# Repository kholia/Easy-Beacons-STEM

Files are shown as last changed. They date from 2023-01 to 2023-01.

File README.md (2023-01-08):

### Easy Beacons

A simple and easy Raspberry Pi Pico powered WSPR, and FT8 beacon system which
uses GPS for timing.

Note: The whole project can be assembled on a breadboard (including the [~100mW
amplifier](./QRPp-Amplifier-v2)) in under an hour - do give it a go!

The whole design is modular, parametric (cost and others), field repairable,
and super extensible. It is almost trivial to add support for more `beacon
modes`.

#### Build Steps

Use a stable version of the Arduino IDE 1.8.19 or later to build the project.

If you are on Linux, execute the following steps:

```
sudo apt-get install git  # install 'git' if needed

git clone https://github.com/kholia/Easy-Beacons-STEM.git

make install_arduino_cli
make install_platform
make deps
```

If you are using Windows OS, execute the following steps:

- Download this repository.

- Extract the downloaded zip file to a folder.

- Run the `setup_arduino_ide.bat` file inside this folder.

Note: Change the following lines in the code to use your values:

```
char message[] = "VU3CER VU3FOE MK68";
char call[] = "VU3FOE";
char loc[] = "MK68";
uint8_t dbm = 27;
```

#### Amplified-WSPR-Beacon

- Do NOT power with more than 8.4v!

- Use an 7.5v AC adapter for continuous use

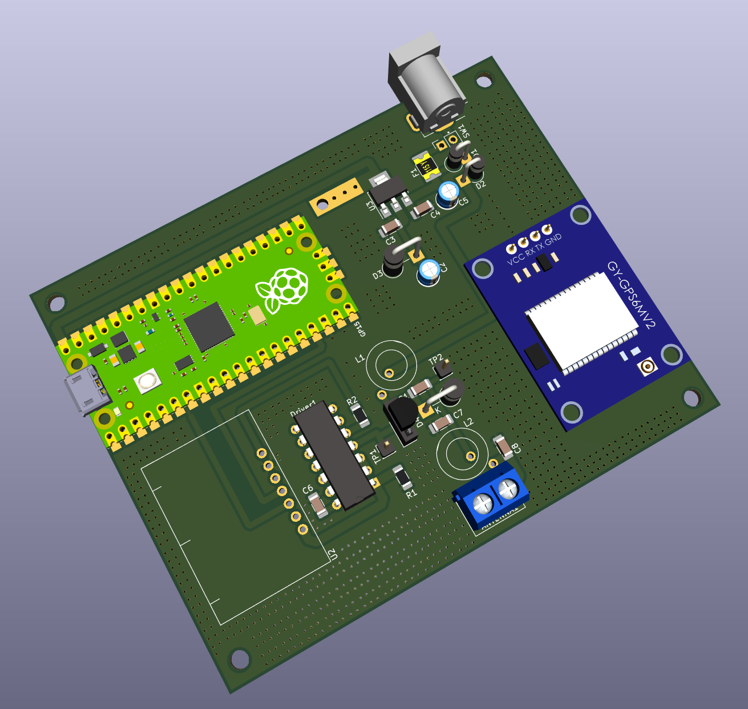
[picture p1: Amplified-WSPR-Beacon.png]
PCB Render


Note: The PCB version of the `Amplified-WSPR-Beacon` sub-project uses the `Pico-Beacons-GPS-v2` firmware (code).

Note 2: The `Amplified-WSPR-Beacon-v2` project uses 5v from USB.

#### Usage

When `SW1` switch is OFF, the system acts as a WSPR beacon.

When `SW1` switch is ON, the system acts as a FT8 beacon.

TIP: Please use a local (or nearby) receiver to receive and decode the beacon
signals! This is important to ensure that your beacon is TX'ing correctly.

#### Schematic

Here is the schematic for the `Pico-Beacons` sketch:

Pin 16 (GP16) is SDA and Pin 17 (GP17) is SCL - connect Si5351 module to these
pins. Connect GPS's TX pin to pin 12 (GP9) of Pi Pico.

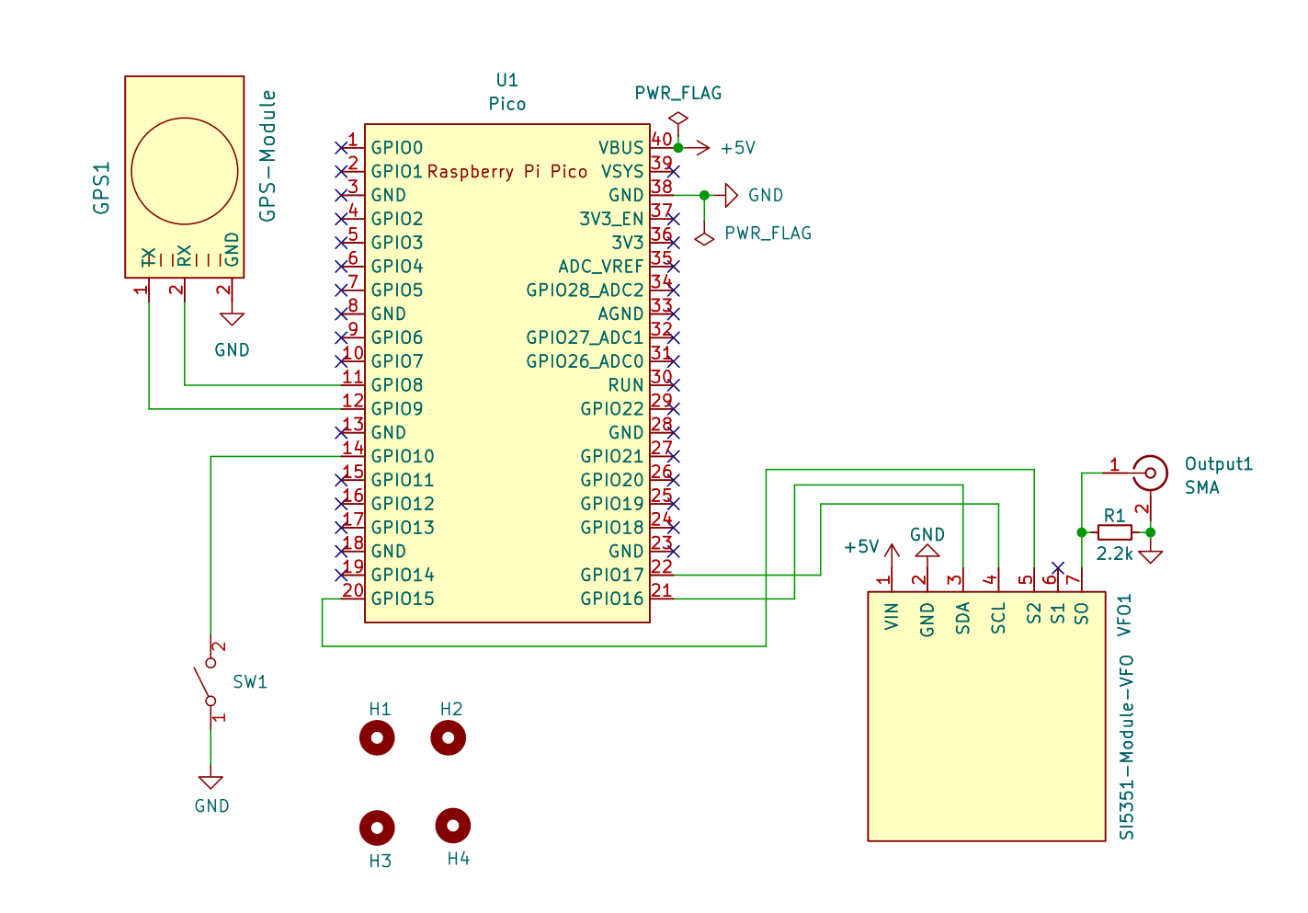
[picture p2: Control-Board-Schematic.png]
Schematic


#### Performance

7W (or less) of HF RF power offers global communications coverage when
propagation is good:

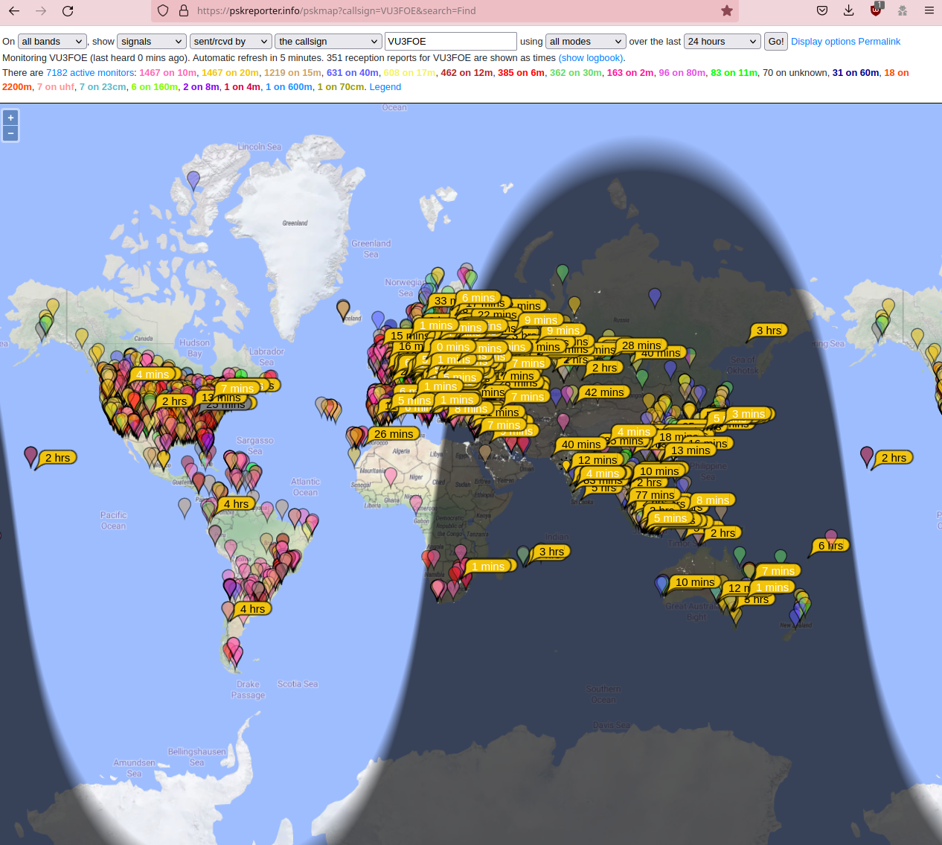
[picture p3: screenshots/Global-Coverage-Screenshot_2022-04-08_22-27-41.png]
Global Coverage

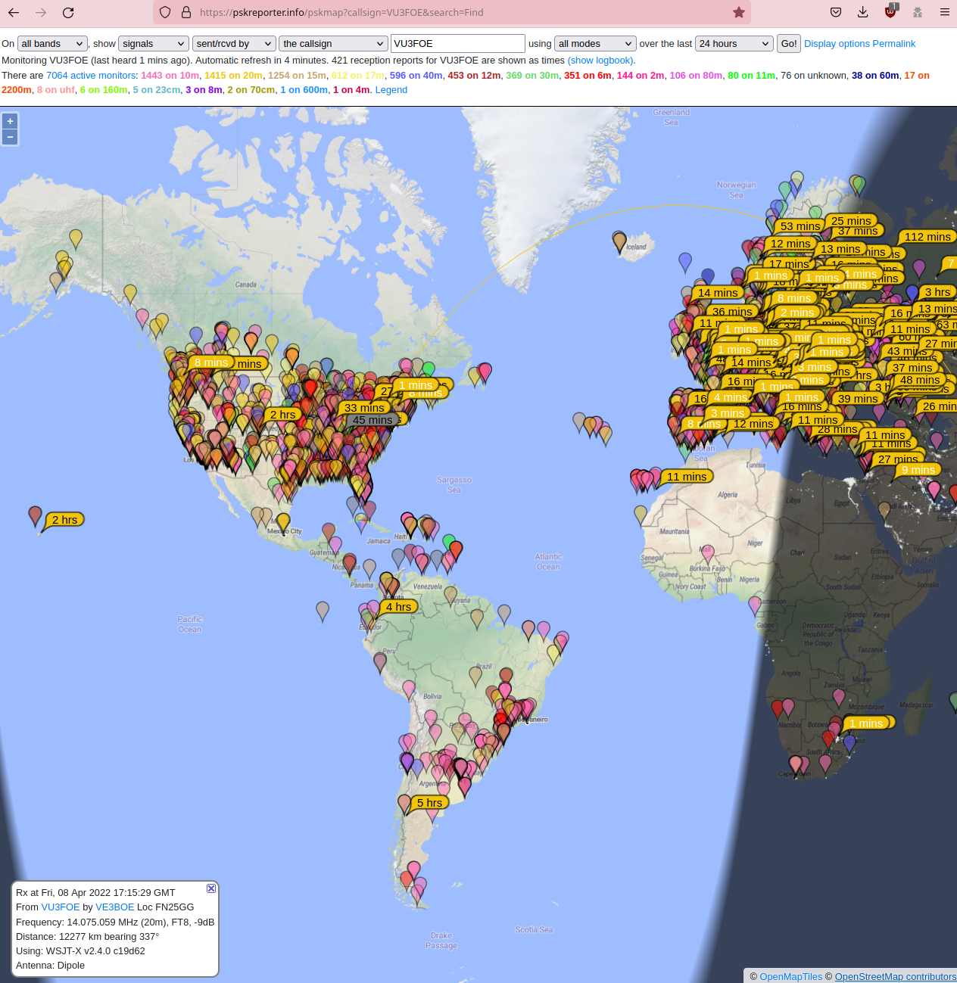
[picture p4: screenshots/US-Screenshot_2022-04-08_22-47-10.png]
US - Many Spots


WSPR mode demo:

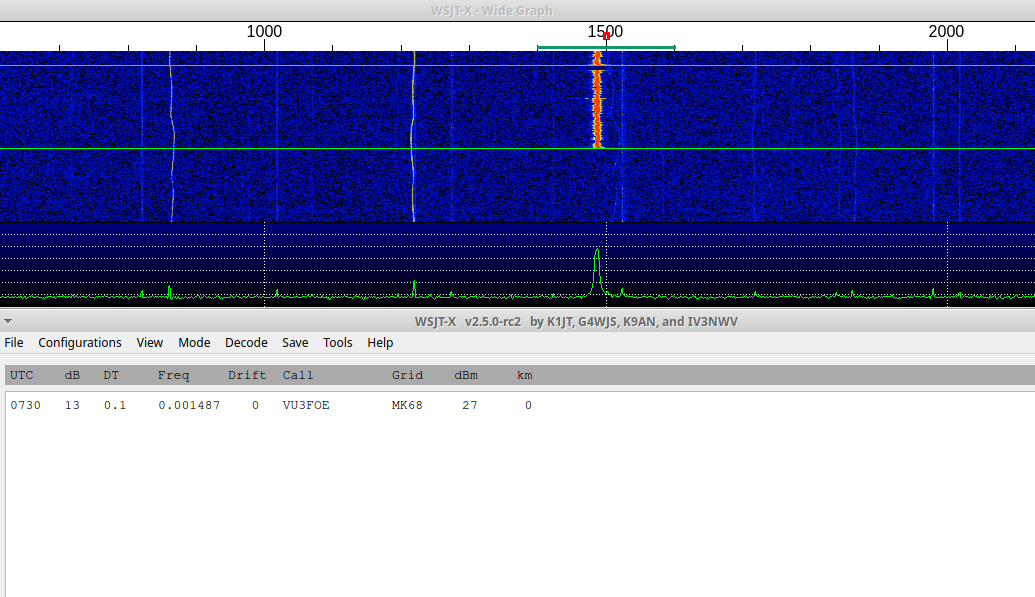
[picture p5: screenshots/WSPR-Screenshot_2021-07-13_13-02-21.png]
DEMO 1


#### Battery System Recommendation

I recommend using a LiFePo4 (LFP) battery which has good energy density and is
also priced decently well.

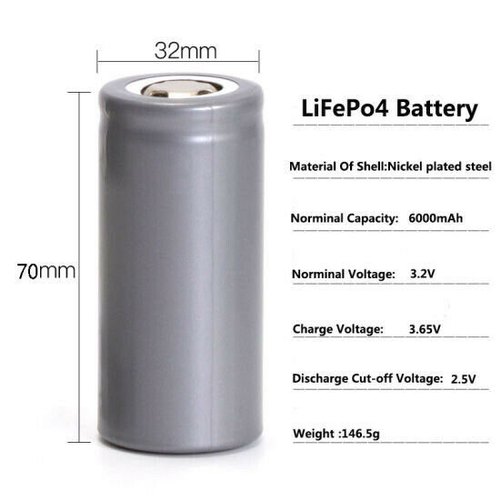
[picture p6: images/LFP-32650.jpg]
32650 battery


Use the LFP battery with a `1S LFP BMS`.

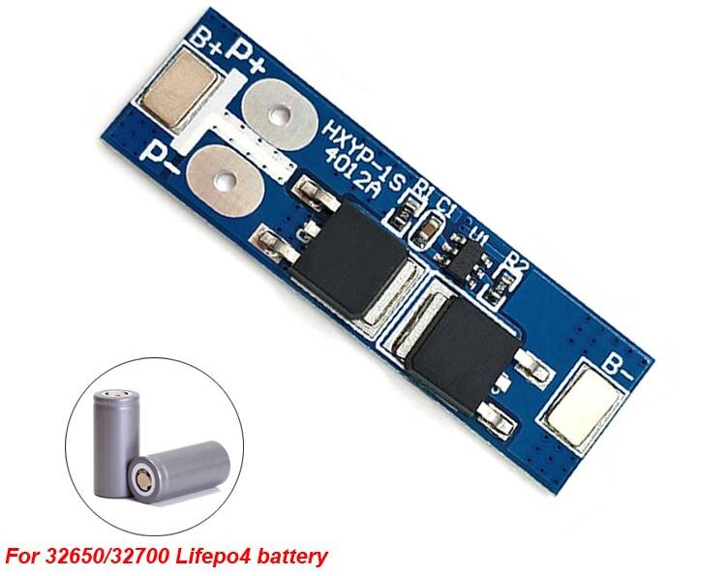
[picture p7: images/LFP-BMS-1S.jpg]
1S LFP BMS


The BMS' output can be connected directly to the 3.3v input of the ESP8266
module.

https://www.waveshare.com/wiki/Solar_Power_Manager - this `Solar Power
Management Module, for 6V~24V Solar Panel` works pretty well.

#### Power Notes

This will need a HF RF PA in many cases to be usable on the air.

You can also start with the easy-to-build and breadboard-friendly [QRPp-Amplifier-v2](./QRPp-Amplifier-v2).

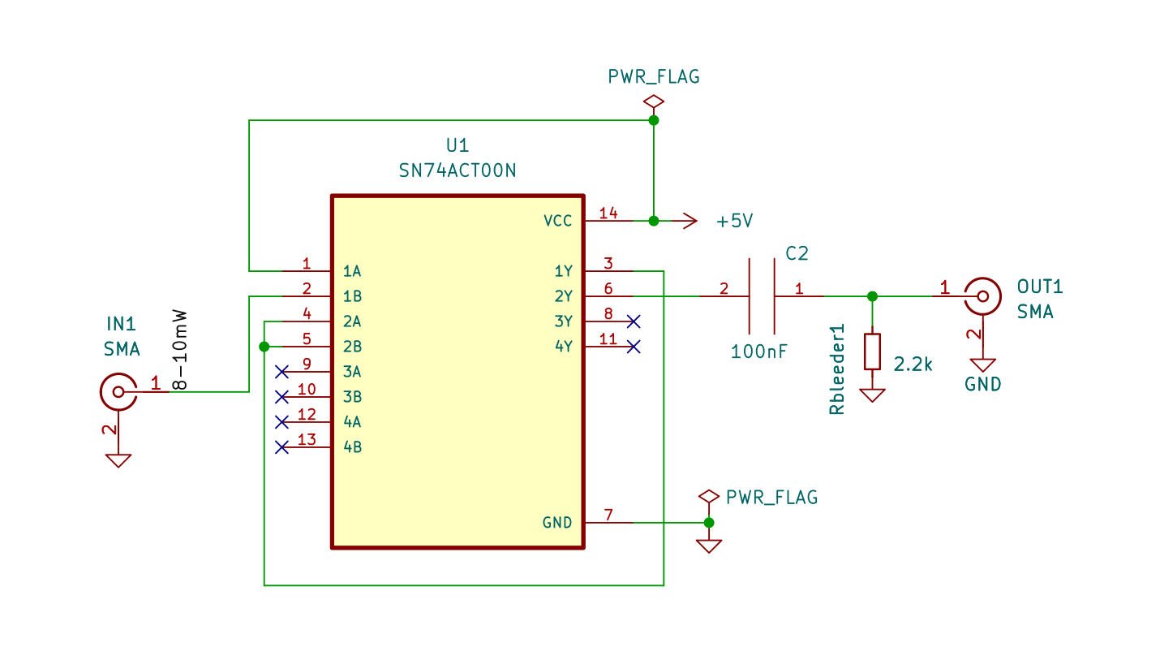
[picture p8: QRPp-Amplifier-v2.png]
QRPp-Amplifier-v2


#### Safety Notes

- Connect a 1k or 2.2k resistor between Si5351 CLK outputs and GND.

- Connect a series 100nF at Si5351 CLK outputs.

- Do NOT connect a LED to the output(s) of Si5351 directly. Use a 330 or 470
  ohm resistor in series or use a transistor driver at the Si5351 outputs
  (better).

#### Compliance Notes

Please use a LPF at the output.

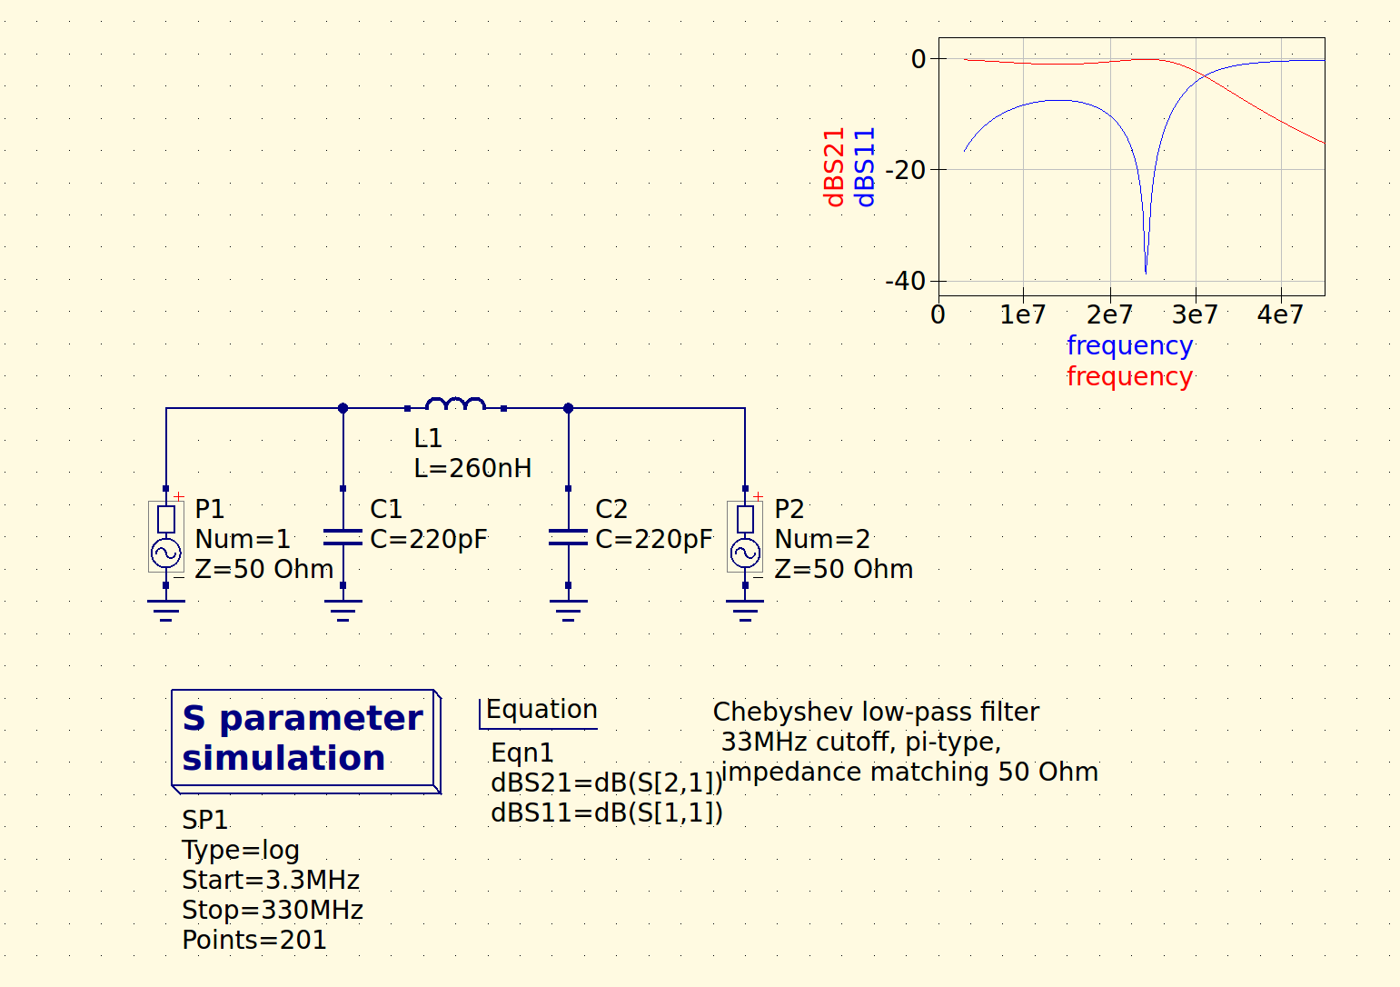
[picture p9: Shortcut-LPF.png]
Shortcut LPF


#### Gotchas

- https://github.com/mikalhart/TinyGPSPlus/issues/30 (NEO-6M modules can be buggy)

#### BOM

- 1 x 3/5mm LED (purple or pink is recommended)

- 1 x small regular (spst) chassis mount switch

- 1 x 0.25w 470 ohm resistor (CFR / MFR)

- High quality dupont cables / jumper cables

- Couple of 100nF 50V MLCC

- Zero PCB of a suitable size

- Raspberry Pi Pico board

- GPS module - NEO-7-M or better

- BS170 MOSFET (original only)

- SN74ACT00N (DIP 14 NAND Logic IC)

- Si5351A Module

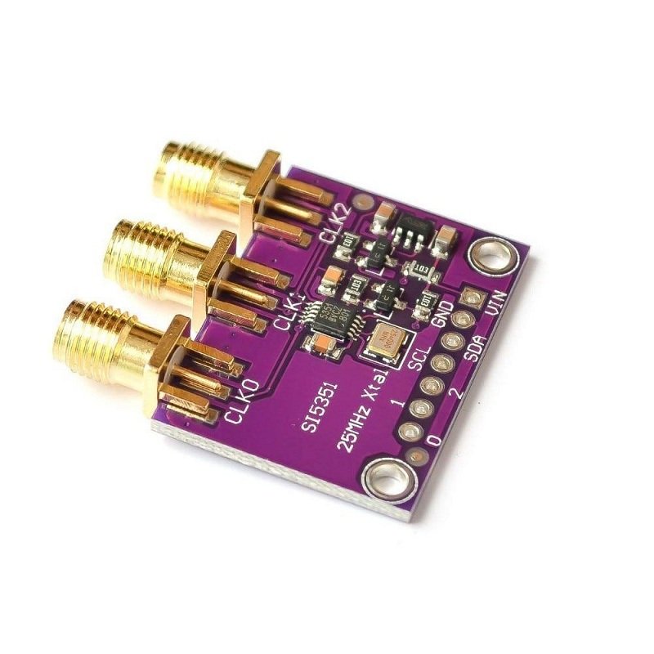
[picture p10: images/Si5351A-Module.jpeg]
Part 1
  

#### Install the firmware on Pi Pico

- Hold down the BOOTSEL button on your Pico (keep holding it down) and plug it
  into your computer's USB port.

  Now release the BOOTSEL button.

- Open Explorer, and open the RPI-RP2 directory like you would any other hard
  drive.

- Drag and drop the UF2 file (`firmware.uf2`) from this folder into the RPI-RP2
  directory.

- Done ;)

#### Build from source

Use the latest Arduino IDE along with https://github.com/earlephilhower/arduino-pico
to build this source code.

#### Next Steps

Check out the ADX and PDX radio designs for added fun!

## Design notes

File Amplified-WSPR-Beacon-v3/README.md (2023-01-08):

### Easy Beacons

A simple and easy Raspberry Pi Pico W powered WSPR, and FT8 beacon system which
uses RTC (DS3231) for timing.

The whole design is modular, parametric (cost and others), field repairable,
and super extensible. It is almost trivial to add support for more `beacon
modes`.

Cost to build: Less than 2300 INR (< 28 USD).

Cost breakdonw: PCB (175) + Si5351 module (479) + Pico W (649) + Octal Driver
chip (85) + Passives (50) + Connectors (25) + Toroids (40) + RTC module (275) +
Wire (30) + Wire Ferrules (10) + Misc (50) + 425 (TR1).

Power output: 250mW even @ 28 MHz with a 5v supply (via USB).

Note: The kit needs to be (soldering) friendly enough - it will be built by
senior folks as well as young kids.

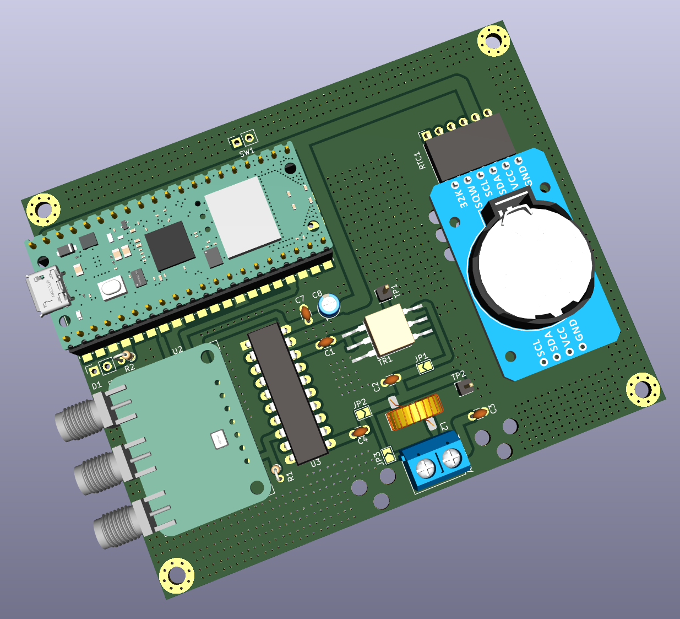
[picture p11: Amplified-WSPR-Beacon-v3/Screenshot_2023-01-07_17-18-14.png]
PCB render


#### Build Steps

Use a stable version of the Arduino IDE 1.8.19 or later to build the project.

If you are on Linux, execute the following steps:

```
sudo apt-get install git  # install 'git' if needed

git clone https://github.com/kholia/Easy-Beacons-STEM.git

make install_arduino_cli
make install_platform
make deps
```

If you are using Windows OS, execute the following steps:

- Download this repository.

- Extract the downloaded zip file to a folder.

- Run the `setup_arduino_ide.bat` file inside this folder.

Note: Change the following lines in the code to use your own values:

```
char call[] = "VU3CER";
char loc[] = "MK68";
uint8_t dbm = 23;
```

#### Amplified-WSPR-Beacon-v3

- Supply 5v to Raspberry Pico W using a mobile (phone) charger or a USB 5v
  battery bank.

Note: The PCB version of the `Amplified-WSPR-Beacon-v3` sub-project uses the
code from the `firmware` folder.

#### Usage

TIP: Please use a local (or nearby) receiver to receive and decode the beacon
signals! This is important to ensure that your beacon is calibrated and TX'ing
correctly.

#### Safety Notes

- Connect a 1k or 2.2k resistor between Si5351 CLK outputs and GND.

- Connect a series 100nF at Si5351 CLK outputs.

- Do NOT connect a LED to the output(s) of Si5351 directly. Use a 330 or 470
  ohm resistor in series or use a transistor driver at the Si5351 outputs
  (better).

#### BOM

- 1 x 3/5mm LED (purple or pink is recommended)

- 1 x 0.25W 2.2k ohms CFR / MFR (resistor)

- Couple of 100nF 50V MLCC caps

- 100uF/16V electrolytic caps

- 220pF C0G MLCC caps

- 27 to 29 SWG copper winding ("magnetic") wire

- PCB Terminal Block (5.08mm spacing, 2 holes)

- Raspberry Pi Pico W board

- DS3231 RTC module

- SN74ACT244N (Fast DIP-20 Octal Driver)

- T2-613-1 IC (1:1:2 transformer IC from Mini-Circuits)

- Si5351A Module (with TCXO preferably)

#### Install the firmware on Pi Pico

- Hold down the BOOTSEL button on your Pico (keep holding it down) and plug it
  into your computer's USB port.

  Now release the BOOTSEL button.

- Open Explorer, and open the RPI-RP2 directory like you would any other hard
  drive.

- Drag and drop the UF2 file (`firmware.uf2`) from this folder into the RPI-RP2
  directory.

- Done ;)

#### Build from source

Use the latest Arduino IDE along with https://github.com/earlephilhower/arduino-pico
to build this source code.

#### Next Steps

Check out the "DDX - Direct Digital Transceiver" design for added fun!

#### Tips

- https://en.wikipedia.org/wiki/Electric_wire_ferrule - Use wire ferrules for the antenna wires

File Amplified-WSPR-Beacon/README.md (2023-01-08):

Output with 7.4v @ drain is around 400mW @ 28 MHz. Not too bad - twice that of
the `Intl. WSPR Beacon` device.

This project is also called the `Rogue Radio - v1` ;)

Cost: < 1800 INR (not including the 2s 18650 battery pack) which is around 22
USD.

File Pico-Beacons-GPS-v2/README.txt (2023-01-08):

This code is for the `PCB version` of `Amplified-WSPR-Beacon` project.

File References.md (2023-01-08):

#### References + Credits

- https://github.com/kholia/Easy-Transceiver

- https://github.com/kgoba/ft8_lib

- https://github.com/etherkit/JTEncode

- https://github.com/Naguissa/uEEPROMLib

- https://randomnerdtutorials.com/esp8266-web-server-spiffs-nodemcu/

- https://lastminuteengineers.com/ds3231-rtc-arduino-tutorial/

- https://learn.adafruit.com/adafruit-si5351-clock-generator-breakout/wiring-and-test

- https://github.com/agustinmartino/wsjt_transceiver

- https://github.com/agustinmartino/wsjtx_transceiver_interface

- https://www.qrp-labs.com/synth/ms5351m.html

- https://github.com/anupamsaikia - FT4 fixes - thanks!

- https://github.com/f4goh/WSPR (pretty cool)

- https://github.com/lu7did/PixiePi

- https://github.com/iw5ejm/multibandWSPR_nodeMCU

- https://km4nmp.com/2019/08/24/vfo-for-the-pixie-wiring-and-sketch-for-ad9850/

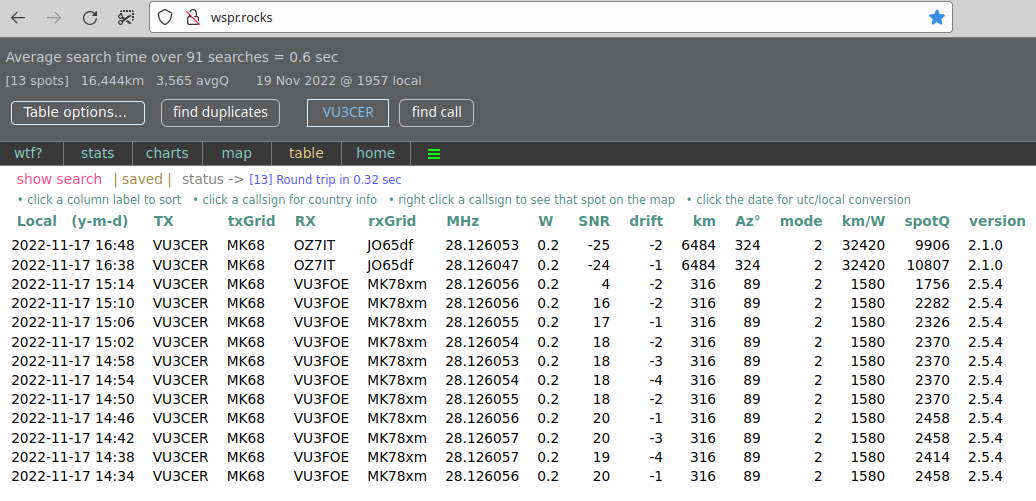
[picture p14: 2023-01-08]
Amplified-WSPR-Beacon/Report-Screenshot_2022-11-19_19-58-08.png

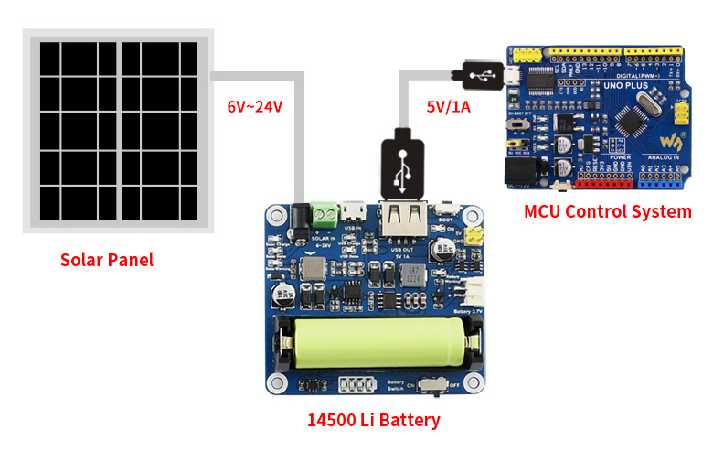
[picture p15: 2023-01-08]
images/Solar-Power-Manager-application.jpg

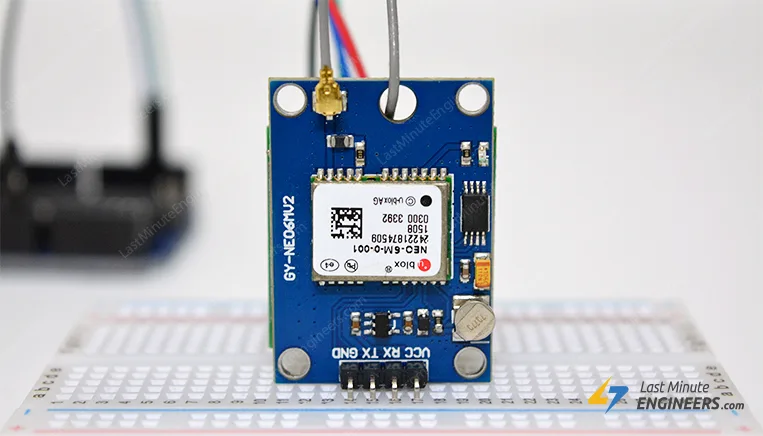
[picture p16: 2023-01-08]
images/NEO-6M-GPS-Module.webp

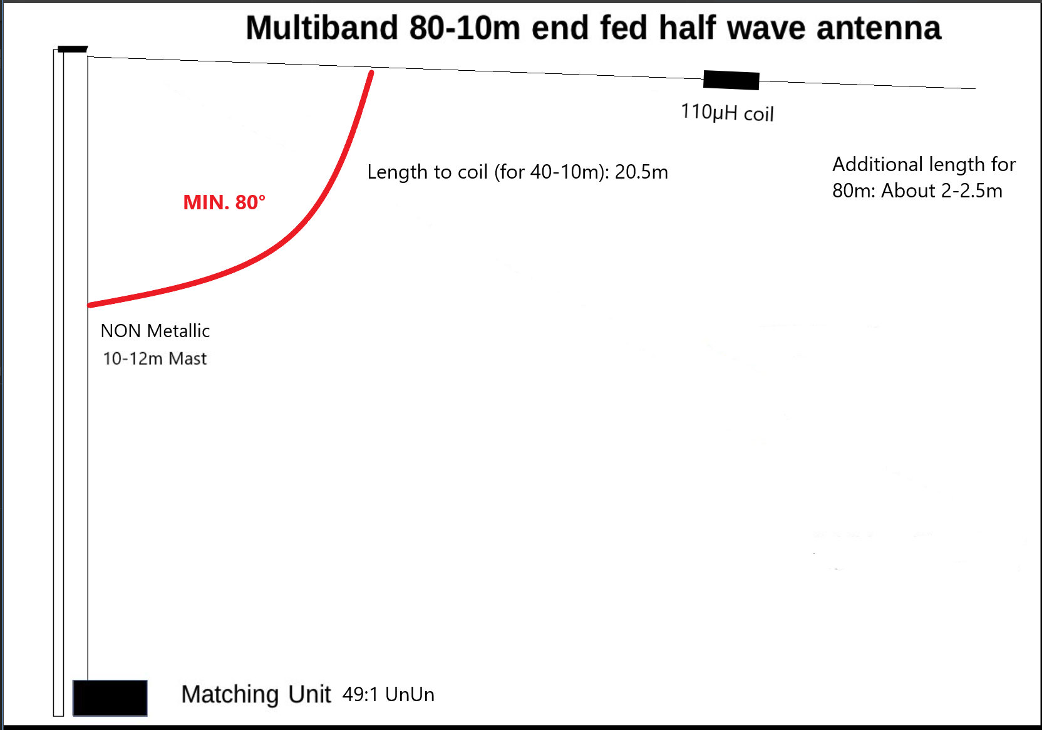
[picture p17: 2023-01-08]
EFHW-1-1.png

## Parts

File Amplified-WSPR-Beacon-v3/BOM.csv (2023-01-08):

Reference | Value | Footprint | Datasheet | Populate | URL | Qty
ANTENNA1 | Screw_Terminal_01x02 | TerminalBlock:TerminalBlock_bornier-2_P5.08mm | ~ | no | https://www.digikey.com/en/products/detail/weidm%C3%BCller/1760510000/459739 | 1
C1, C4, C7 | 100nF | Capacitor_THT:C_Disc_D3.0mm_W1.6mm_P2.50mm | ~ | no | https://www.digikey.com/en/products/detail/vishay-beyschlag-draloric-bc-components/K104K15X7RF5TL2/286538 | 3
C2, C3 | 220p | Capacitor_THT:C_Disc_D3.0mm_W1.6mm_P2.50mm | ~ | yes | https://www.digikey.in/en/products/detail/vishay-beyschlag-draloric-bc-components/K221J15C0GF5TL2/286471 | 2
C8 | 100uF/16V | Capacitor_THT:CP_Radial_D4.0mm_P2.00mm | ~ |  | https://www.digikey.com/en/products/detail/rubycon/16ZLH100MEFC5X11/3134106 | 1
D1 | LED | Connector_PinSocket_2.54mm:PinSocket_1x02_P2.54mm_Vertical | ~ |  |  | 1
H1-H4 | MountingHole_Pad | MountingHole:MountingHole_3.2mm_M3_Pad_Via | ~ |  |  | 4
JP1-JP3 | Jumper_2_Open | Jumper:SolderJumper-2_P1.3mm_Open_TrianglePad1.0x1.5mm | ~ |  |  | 3
L2 | 260nH (T50-6, ~8 turns) | footprints:T37-2 | https://toroids.info/T50-6.php | no | https://kitsandparts.com/ | 1
R1 | 2.2k | Resistor_THT:R_Axial_DIN0204_L3.6mm_D1.6mm_P1.90mm_Vertical | ~ | yes | https://www.digikey.com/en/products/detail/stackpole-electronics-inc/RNMF14FTC2K20/2617325 | 1
R2 | 470 | Resistor_THT:R_Axial_DIN0204_L3.6mm_D1.6mm_P1.90mm_Vertical | ~ |  | https://www.digikey.com/en/products/detail/yageo/MF0207FRE52-470R/9125108 | 1
RTC1 | RTC_DS3231_Inverted | Connector_PinSocket_2.54mm:PinSocket_1x06_P2.54mm_Horizontal |  | no | https://robu.in/product/1x40-berg-strip-right-angle-female-connector-5pcs/ | 1
TP1, TP2 | TestPoint | Connector_PinHeader_2.54mm:PinHeader_1x01_P2.54mm_Vertical | ~ | no | https://robu.in/product/1x40-berg-strip-male-connector/ | 2
TR1 | T2-613-1+ | footprints:KK81 | ~ |  | https://www.minicircuits.com/WebStore/dashboard.html?model=T2-613-1-KK81%2B | 1
U1 | Pico | footprints:RPi_Pico_SMD_TH |  | no | https://www.digikey.com/en/products/detail/raspberry-pi/SC0918/16608263 | 1
U2 | SI5351-Module-VFO (With TCXO) | footprints:SI5351 Module |  | no | https://www.adafruit.com/product/2045 | 1
U3 | 74ACT244 | Package_DIP:DIP-20_W7.62mm_LongPads | https://www.ti.com/product/SN74ACT244 | no | https://www.digikey.com/en/products/detail/texas-instruments/SN74ACT244N/375910 | 1

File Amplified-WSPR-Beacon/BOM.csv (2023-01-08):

Source: | Easy-Beacons-STEM/Amplified-WSPR-Beacon/Amplified-WSPR-Beacon.kicad_sch
Date: | Sun 20 Nov 2022 02:35:45 PM IST
Tool: | Eeschema 6.0.9-8da3e8f707~116~ubuntu22.04.1
Generator: | /usr/share/kicad/plugins/bom_csv_grouped_by_value.py
Component Count: | 33
Individual Components:
Item | Qty | Reference(s) | Value | LibPart | Footprint | Datasheet | Populate | URL
 |  | ANTENNA1 | Screw_Terminal_01x02 | Connector:Screw_Terminal_01x02 | TerminalBlock:TerminalBlock_bornier-2_P5.08mm | ~ | no | https://www.digikey.com/en/products/detail/weidm%C3%BCller/1760510000/459739
 |  | C1 | 100nF | Device:C | Capacitor_SMD:C_1206_3216Metric_Pad1.33x1.80mm_HandSolder | ~ | yes | https://www.digikey.com/en/products/detail/yageo/CC1206KRX7R9BB104/302913
 |  | C2 | 10uF/16V | Device:C_Polarized | Capacitor_THT:CP_Radial_D4.0mm_P2.00mm | ~ | no | https://www.digikey.com/en/products/detail/nichicon/UVR1C100MDD/588777
 |  | C3 | 100nF | Device:C | Capacitor_SMD:C_1206_3216Metric_Pad1.33x1.80mm_HandSolder | ~ | yes | https://www.digikey.com/en/products/detail/yageo/CC1206KRX7R9BB104/302913
 |  | C4 | 100nF | Device:C | Capacitor_SMD:C_1206_3216Metric_Pad1.33x1.80mm_HandSolder | ~ | yes | https://www.digikey.com/en/products/detail/yageo/CC1206KRX7R9BB104/302913
 |  | C5 | 100uF/16V | Device:C_Polarized | Capacitor_THT:CP_Radial_D4.0mm_P2.00mm | ~ | no | https://www.digikey.com/en/products/detail/rubycon/16YXF100MEFC6-3X11/3563101
 |  | C6 | 100nF | Device:C_Small | Capacitor_SMD:C_1206_3216Metric_Pad1.33x1.80mm_HandSolder | ~ | yes | https://www.digikey.com/en/products/detail/yageo/CC1206KRX7R9BB104/302913
 |  | C7 | 220p | Device:C_Small | Capacitor_SMD:C_1206_3216Metric_Pad1.33x1.80mm_HandSolder | ~ | yes | https://www.digikey.com/en/products/detail/yageo/CC1206JRNPO9BN221/2833598
 |  | C8 | 220p | Device:C_Small | Capacitor_SMD:C_1206_3216Metric_Pad1.33x1.80mm_HandSolder | ~ | yes | https://www.digikey.com/en/products/detail/yageo/CC1206JRNPO9BN221/2833598
 |  | D1 | 1N4007 | Diode:1N4007 | Diode_THT:D_DO-41_SOD81_P2.54mm_Vertical_KathodeUp | http://www.vishay.com/docs/88503/1n4001.pdf | no | https://www.digikey.com/en/products/detail/diodes-incorporated/1N4007-T/607
 |  | D2 | 1N4007 | Diode:1N4007 | Diode_THT:D_DO-41_SOD81_P2.54mm_Vertical_KathodeUp | http://www.vishay.com/docs/88503/1n4001.pdf | no | https://www.digikey.com/en/products/detail/diodes-incorporated/1N4007-T/607
 |  | D3 | 5.6V 5W | Device:D_Zener | Diode_THT:D_DO-15_P5.08mm_Vertical_KathodeUp | ~ | no | https://www.digikey.com/en/products/detail/onsemi/1N5339BRLG/822783
 |  | D4 | 47v 5W | Device:D_Zener | Diode_THT:D_DO-15_P5.08mm_Vertical_KathodeUp | ~ | no | https://www.digikey.in/en/products/detail/onsemi/1N5368BG/13476793
 |  | Driver1 | SN74ACT04N | SN74HC04N:SN74HC04N | Package_DIP:DIP-14_W7.62mm |  | no | https://www.digikey.com/en/products/detail/texas-instruments/SN74ACT04N/375794
 |  | F1 | 1A (PPTC) | Device:Polyfuse_Small | Fuse:Fuse_1812_4532Metric_Pad1.30x3.40mm_HandSolder | ~ | yes | https://www.digikey.com/en/products/detail/bourns-inc/MF-MSMF110-16-2/662820
 |  | GPS3 | GY-NEO6MV2-Module | GPS-Module:GPS-Module | Connector_PinSocket_2.54mm:PinSocket_1x04_P2.54mm_Vertical |  | no | https://quartzcomponents.com/products/neo6mv2-gps-module-with-flight-controller
 |  | H1 | MountingHole | Mechanical:MountingHole | MountingHole:MountingHole_3.2mm_M3 | ~ | no | N/A
 |  | H2 | MountingHole | Mechanical:MountingHole | MountingHole:MountingHole_3.2mm_M3 | ~ | no | N/A
 |  | H3 | MountingHole | Mechanical:MountingHole | MountingHole:MountingHole_3.2mm_M3 | ~ | no | N/A
 |  | H4 | MountingHole | Mechanical:MountingHole | MountingHole:MountingHole_3.2mm_M3 | ~ | no | N/A
 |  | HS1 | Heatsink_Pad | Mechanical:Heatsink_Pad | footprints:ThermalPad_Final | ~ | no | N/A
 |  | L1 | L | Device:L | footprints:FT37-INDUCTOR | FT37-43 | no | https://kitsandparts.com/
 |  | L2 | 260nH (T50-2, ~8 turns) | Device:L | footprints:FT37-INDUCTOR | FT50-2 | no | https://kitsandparts.com/
 |  | Power1 | DC-005 (Barrel Jack) | Connector:Barrel_Jack_Switch | footprints:XKB_DC-005-5A-2.0_Modded | ~ | no | https://www.lcsc.com/product-detail/Power-Connectors_XKB-Enterprise-DC-005-5A-2-0_C381116.html
 |  | Q1 | BS170 | Transistor_FET:BS170 | Connector_PinSocket_2.54mm:PinSocket_1x03_P2.54mm_Vertical | https://www.onsemi.com/pub/Collateral/BS170-D.PDF | no | https://www.tme.eu/en/details/bs170/tht-n-channel-transistors/onsemi/
 |  | R1 | 2.2k | Device:R_Small | Resistor_SMD:R_1206_3216Metric_Pad1.30x1.75mm_HandSolder | ~ | yes | https://www.digikey.com/en/products/detail/yageo/RT1206FRE072K2L/1083103
 |  | R2 | 2.2k | Device:R_Small | Resistor_SMD:R_1206_3216Metric_Pad1.30x1.75mm_HandSolder | ~ | yes | https://www.digikey.com/en/products/detail/yageo/RT1206FRE072K2L/1083103
 |  | SW1 | Jumper_2_Open | Jumper:Jumper_2_Open | Connector_PinSocket_2.54mm:PinSocket_1x02_P2.54mm_Vertical | ~ | no | https://www.digikey.com/en/products/detail/sullins-connector-solutions/QPC02SXGN-RC/2618262
 |  | TP1 | TestPoint | Connector:TestPoint | Connector_PinHeader_2.54mm:PinHeader_1x01_P2.54mm_Vertical | ~ | no | https://robu.in/product/1x40-berg-strip-male-connector/
 |  | TP2 | TestPoint | Connector:TestPoint | Connector_PinHeader_2.54mm:PinHeader_1x01_P2.54mm_Vertical | ~ | no | https://robu.in/product/1x40-berg-strip-male-connector/
 |  | U1 | Pico | pico_fixed:Pico | footprints:RPi_Pico_SMD_TH |  | no | https://www.digikey.com/en/products/detail/raspberry-pi/SC0915/13624793
 |  | U2 | SI5351-Module-VFO | Control-Board-rescue:SI5351Module_2-VFO-SDR_SSB-rescue-Hack-v1-rescue | footprints:SI5351 Module |  | no | https://www.adafruit.com/product/2045
 |  | U3 | NCP1117-5.0 | Regulator_Linear:AMS1117-5.0 | Package_TO_SOT_SMD:SOT-223-3_TabPin2 | http://www.advanced-monolithic.com/pdf/ds1117.pdf | yes | https://www.tme.com/in/en/details/ncp1117st50t3g/ldo-unregulated-voltage-regulators/onsemi/
Collated Components:
Item | Qty | Reference(s) | Value | LibPart | Footprint | Datasheet | Populate | URL
1 | 1 | ANTENNA1 | Screw_Terminal_01x02 | Connector:Screw_Terminal_01x02 | TerminalBlock:TerminalBlock_bornier-2_P5.08mm | ~ | no | https://www.digikey.com/en/products/detail/weidm%C3%BCller/1760510000/459739
2 | 3 | C1, C3, C4 | 100nF | Device:C | Capacitor_SMD:C_1206_3216Metric_Pad1.33x1.80mm_HandSolder | ~ | yes | https://www.digikey.com/en/products/detail/yageo/CC1206KRX7R9BB104/302913
3 | 1 | C2 | 10uF/16V | Device:C_Polarized | Capacitor_THT:CP_Radial_D4.0mm_P2.00mm | ~ | no | https://www.digikey.com/en/products/detail/nichicon/UVR1C100MDD/588777
4 | 1 | C5 | 100uF/16V | Device:C_Polarized | Capacitor_THT:CP_Radial_D4.0mm_P2.00mm | ~ | no | https://www.digikey.com/en/products/detail/rubycon/16YXF100MEFC6-3X11/3563101
5 | 1 | C6 | 100nF | Device:C_Small | Capacitor_SMD:C_1206_3216Metric_Pad1.33x1.80mm_HandSolder | ~ | yes | https://www.digikey.com/en/products/detail/yageo/CC1206KRX7R9BB104/302913
6 | 2 | C7, C8 | 220p | Device:C_Small | Capacitor_SMD:C_1206_3216Metric_Pad1.33x1.80mm_HandSolder | ~ | yes | https://www.digikey.com/en/products/detail/yageo/CC1206JRNPO9BN221/2833598
7 | 2 | D1, D2 | 1N4007 | Diode:1N4007 | Diode_THT:D_DO-41_SOD81_P2.54mm_Vertical_KathodeUp | http://www.vishay.com/docs/88503/1n4001.pdf | no | https://www.digikey.com/en/products/detail/diodes-incorporated/1N4007-T/607
8 | 1 | D3 | 5.6V 5W | Device:D_Zener | Diode_THT:D_DO-15_P5.08mm_Vertical_KathodeUp | ~ | no | https://www.digikey.com/en/products/detail/onsemi/1N5339BRLG/822783
9 | 1 | D4 | 47v 5W | Device:D_Zener | Diode_THT:D_DO-15_P5.08mm_Vertical_KathodeUp | ~ | no | https://www.digikey.in/en/products/detail/onsemi/1N5368BG/13476793
10 | 1 | Driver1 | SN74ACT04N | SN74HC04N:SN74HC04N | Package_DIP:DIP-14_W7.62mm |  | no | https://www.digikey.com/en/products/detail/texas-instruments/SN74ACT04N/375794
11 | 1 | F1 | 1A (PPTC) | Device:Polyfuse_Small | Fuse:Fuse_1812_4532Metric_Pad1.30x3.40mm_HandSolder | ~ | yes | https://www.digikey.com/en/products/detail/bourns-inc/MF-MSMF110-16-2/662820
12 | 1 | GPS3 | GY-NEO6MV2-Module | GPS-Module:GPS-Module | Connector_PinSocket_2.54mm:PinSocket_1x04_P2.54mm_Vertical |  | no | https://quartzcomponents.com/products/neo6mv2-gps-module-with-flight-controller
13 | 4 | H1, H2, H3, H4 | MountingHole | Mechanical:MountingHole | MountingHole:MountingHole_3.2mm_M3 | ~ | no | N/A
14 | 1 | HS1 | Heatsink_Pad | Mechanical:Heatsink_Pad | footprints:ThermalPad_Final | ~ | no | N/A
15 | 1 | L1 | L | Device:L | footprints:FT37-INDUCTOR | FT37-43 | no | https://kitsandparts.com/
16 | 1 | L2 | 260nH (T50-2, ~8 turns) | Device:L | footprints:FT37-INDUCTOR | FT50-2 | no | https://kitsandparts.com/
17 | 1 | Power1 | DC-005 (Barrel Jack) | Connector:Barrel_Jack_Switch | footprints:XKB_DC-005-5A-2.0_Modded | ~ | no | https://www.lcsc.com/product-detail/Power-Connectors_XKB-Enterprise-DC-005-5A-2-0_C381116.html
18 | 1 | Q1 | BS170 | Transistor_FET:BS170 | Connector_PinSocket_2.54mm:PinSocket_1x03_P2.54mm_Vertical | https://www.onsemi.com/pub/Collateral/BS170-D.PDF | no | https://www.tme.eu/en/details/bs170/tht-n-channel-transistors/onsemi/
19 | 2 | R1, R2 | 2.2k | Device:R_Small | Resistor_SMD:R_1206_3216Metric_Pad1.30x1.75mm_HandSolder | ~ | yes | https://www.digikey.com/en/products/detail/yageo/RT1206FRE072K2L/1083103
20 | 1 | SW1 | Jumper_2_Open | Jumper:Jumper_2_Open | Connector_PinSocket_2.54mm:PinSocket_1x02_P2.54mm_Vertical | ~ | no | https://www.digikey.com/en/products/detail/sullins-connector-solutions/QPC02SXGN-RC/2618262
21 | 2 | TP1, TP2 | TestPoint | Connector:TestPoint | Connector_PinHeader_2.54mm:PinHeader_1x01_P2.54mm_Vertical | ~ | no | https://robu.in/product/1x40-berg-strip-male-connector/
22 | 1 | U1 | Pico | pico_fixed:Pico | footprints:RPi_Pico_SMD_TH |  | no | https://www.digikey.com/en/products/detail/raspberry-pi/SC0915/13624793
23 | 1 | U2 | SI5351-Module-VFO | Control-Board-rescue:SI5351Module_2-VFO-SDR_SSB-rescue-Hack-v1-rescue | footprints:SI5351 Module |  | no | https://www.adafruit.com/product/2045
24 | 1 | U3 | NCP1117-5.0 | Regulator_Linear:AMS1117-5.0 | Package_TO_SOT_SMD:SOT-223-3_TabPin2 | http://www.advanced-monolithic.com/pdf/ds1117.pdf | yes | https://www.tme.com/in/en/details/ncp1117st50t3g/ldo-unregulated-voltage-regulators/onsemi/

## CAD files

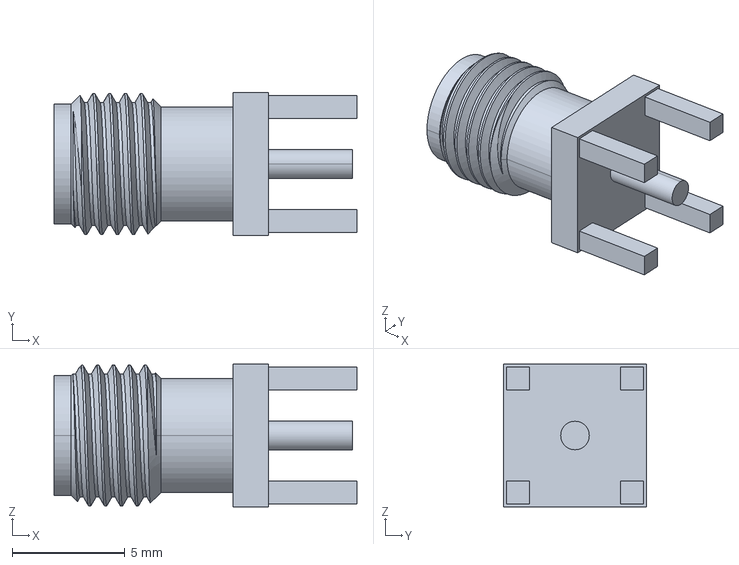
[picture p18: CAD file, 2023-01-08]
Amplified-WSPR-Beacon-v3/models/901-144.stp
13.5 x 6.35 x 6.35 mm

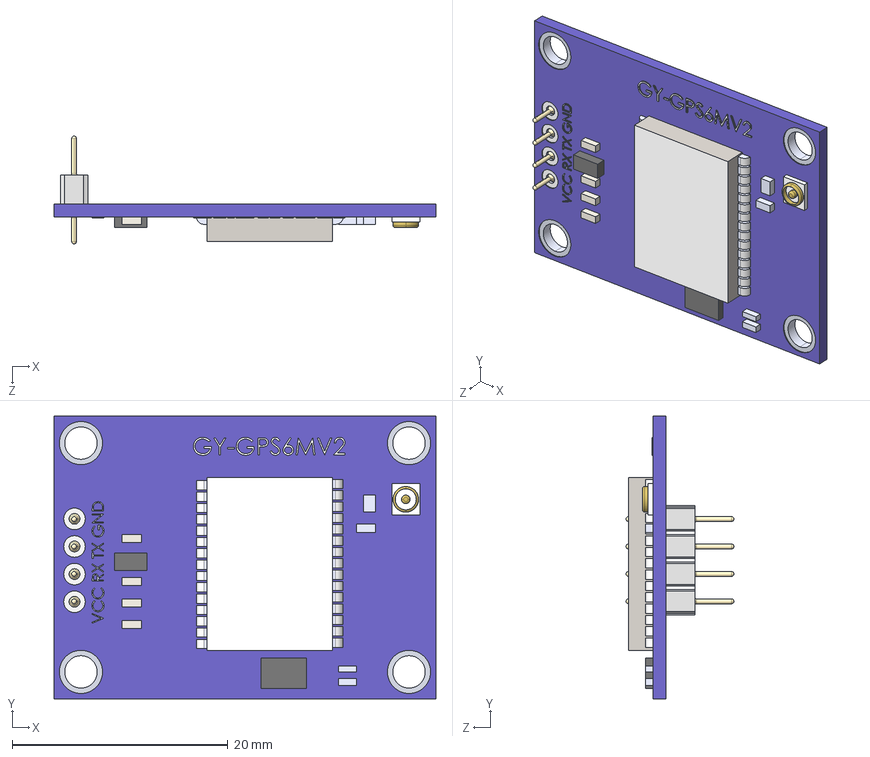
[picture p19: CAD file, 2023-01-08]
Amplified-WSPR-Beacon/models/GY-GPS6MV2 v1.STEP
35.4 x 26.2 x 10.0 mm

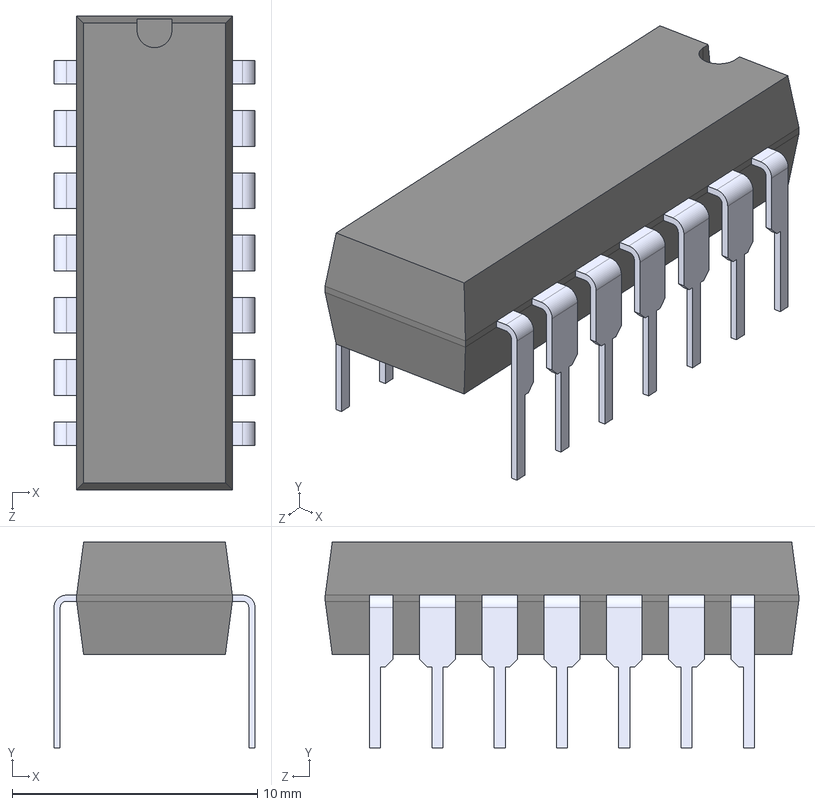
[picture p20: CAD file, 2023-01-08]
Amplified-WSPR-Beacon/SN74HC04N.step
8.19 x 8.38 x 19.3 mm

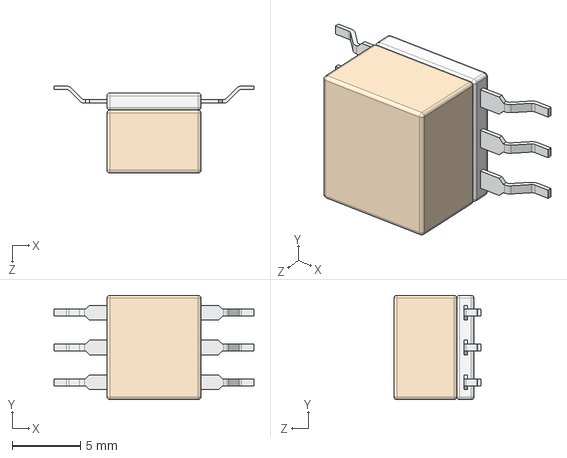
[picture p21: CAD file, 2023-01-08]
Amplified-WSPR-Beacon-v3/models/User Library-T4-6-KK81.STEP
14.6 x 7.62 x 6.35 mm

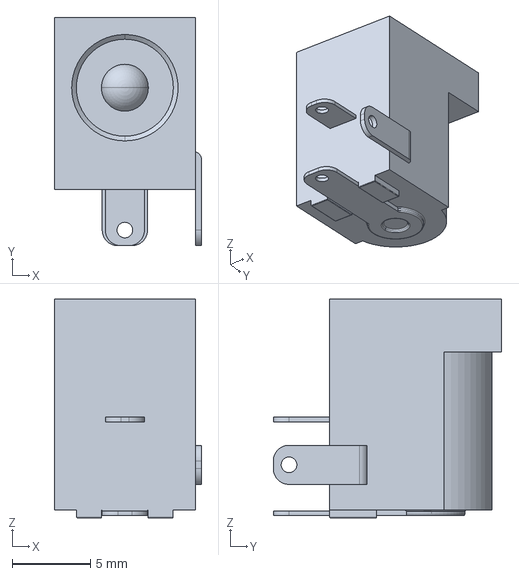
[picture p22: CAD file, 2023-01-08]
Amplified-WSPR-Beacon/models/DC-005-5A-2.0.step
9.40 x 14.6 x 14.0 mm

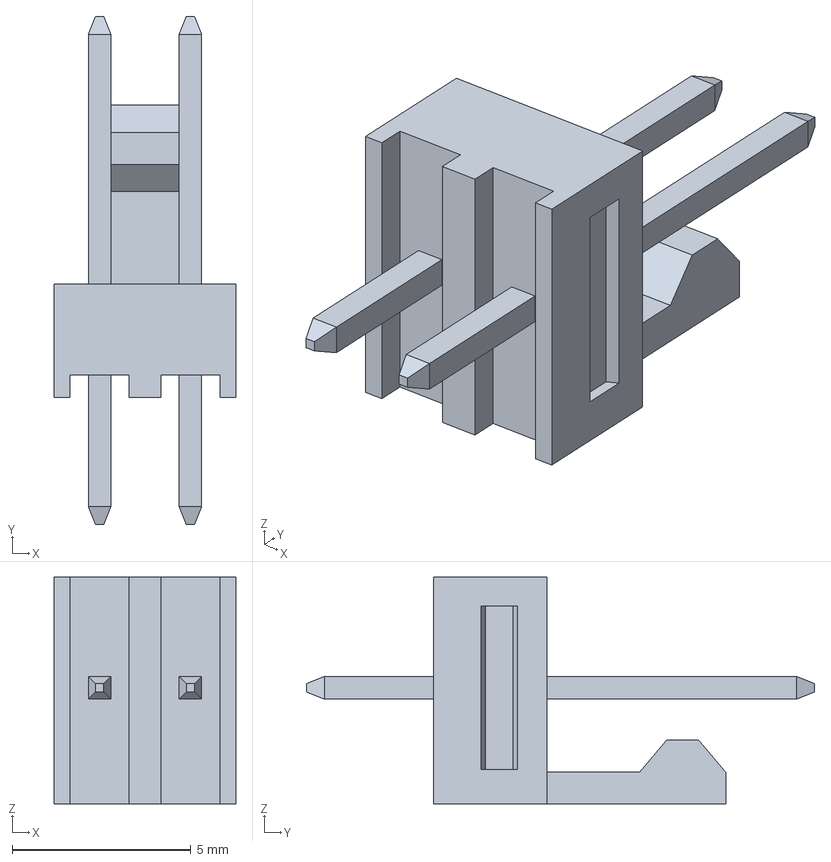
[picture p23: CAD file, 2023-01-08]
Amplified-WSPR-Beacon-v3/models/22-23-2021.stp
5.08 x 14.2 x 6.35 mm

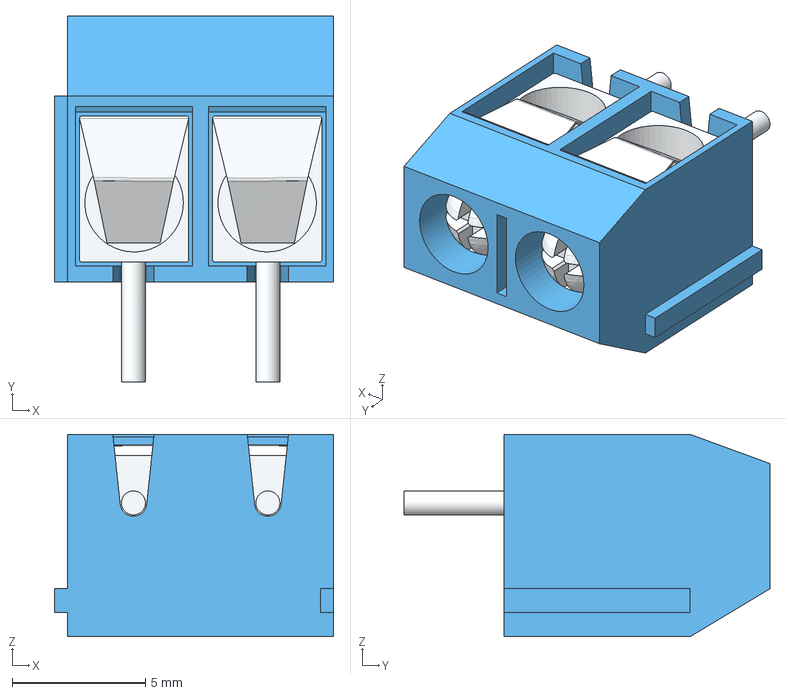
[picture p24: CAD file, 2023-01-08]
Amplified-WSPR-Beacon/models/bornera.step
10.5 x 13.8 x 7.60 mm

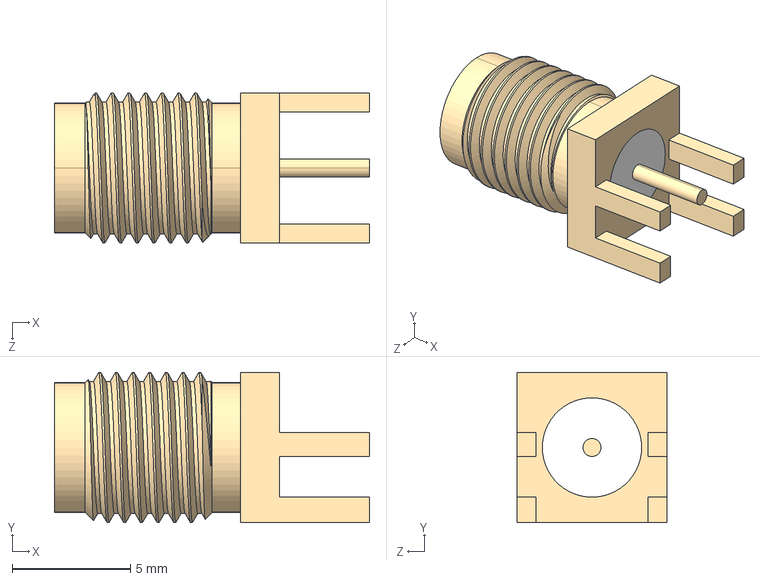
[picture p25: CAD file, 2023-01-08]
Amplified-WSPR-Beacon/models/CON-SMA-EDGE-S--3DModel-STEP-56544.STEP
13.3 x 6.35 x 6.35 mm

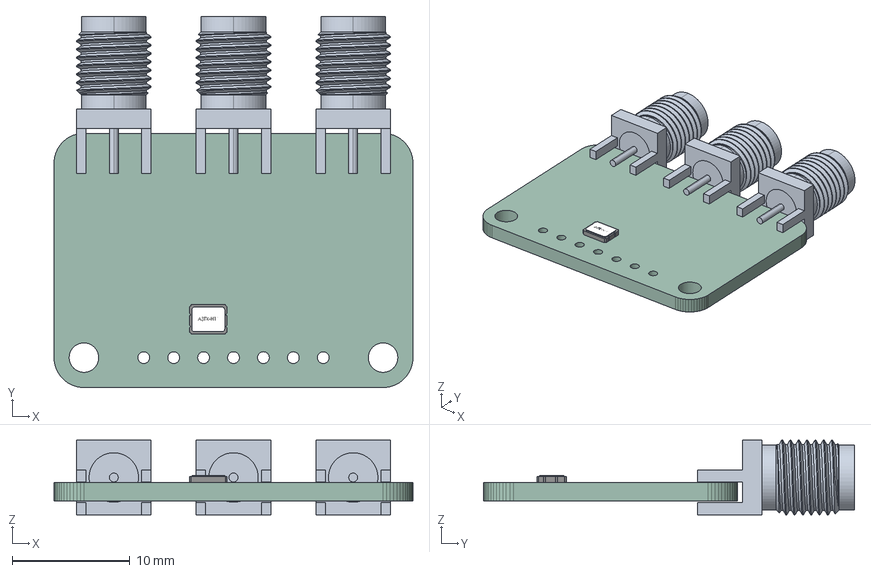
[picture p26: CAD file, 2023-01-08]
Amplified-WSPR-Beacon-v3/models/Adafruit Si5351A.step
30.5 x 31.5 x 6.35 mm
PCB

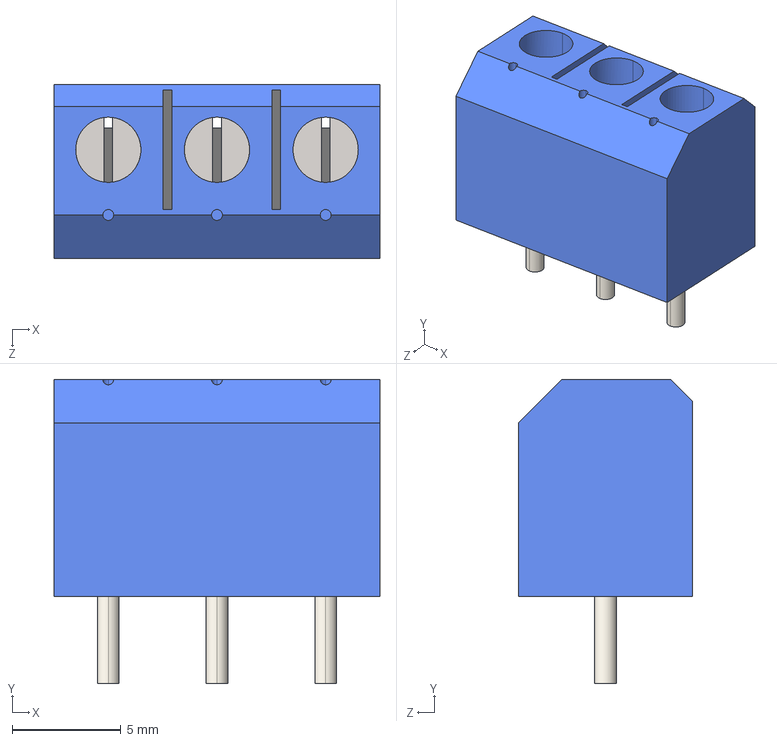
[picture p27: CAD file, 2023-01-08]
Amplified-WSPR-Beacon-v3/models/bornera de 3 terminales v2.0.STEP
15.0 x 14.0 x 8.00 mm

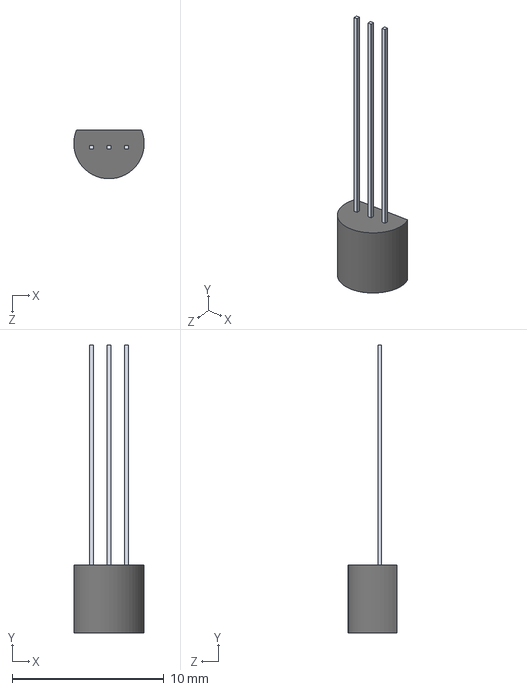
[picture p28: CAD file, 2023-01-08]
Amplified-WSPR-Beacon/models/Transistor_TO-92_Type.STEP
4.64 x 19.0 x 3.20 mm

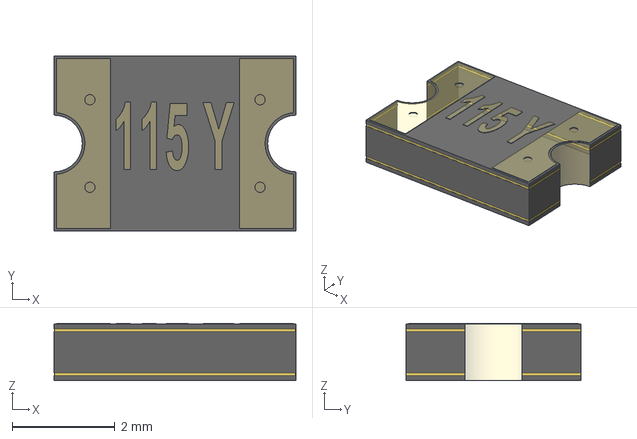
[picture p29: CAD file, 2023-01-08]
Amplified-WSPR-Beacon/models/smd1812.stp
4.70 x 3.40 x 1.11 mm

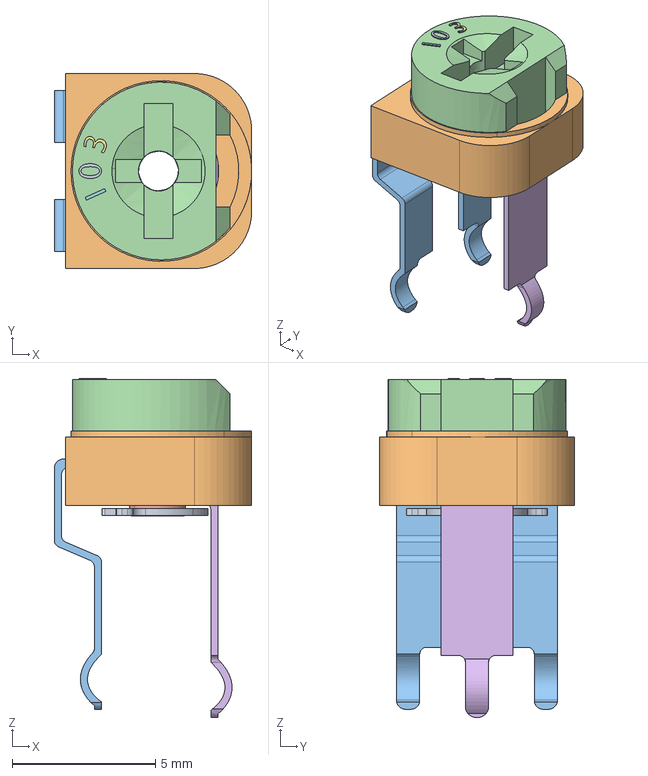
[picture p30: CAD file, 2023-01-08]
Amplified-WSPR-Beacon/models/Poti_10kohm.stp
6.88 x 6.80 x 11.8 mm

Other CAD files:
Amplified-WSPR-Beacon-v2/models/1564889-62.stp
Amplified-WSPR-Beacon-v2/models/1566143-62.stp
Amplified-WSPR-Beacon-v3/models/1564889-62.stp
Amplified-WSPR-Beacon-v3/models/1566143-62.stp
Amplified-WSPR-Beacon/models/1564889-62.stp
Amplified-WSPR-Beacon/models/1566143-62.stp
Amplified-WSPR-Beacon/models/24DR.STEP
Amplified-WSPR-Beacon/models/N0016A.stp
Amplified-WSPR-Beacon/models/User Library-TO-92-2_54-line.STEP
Amplified-WSPR-Beacon/models/pj-307.step

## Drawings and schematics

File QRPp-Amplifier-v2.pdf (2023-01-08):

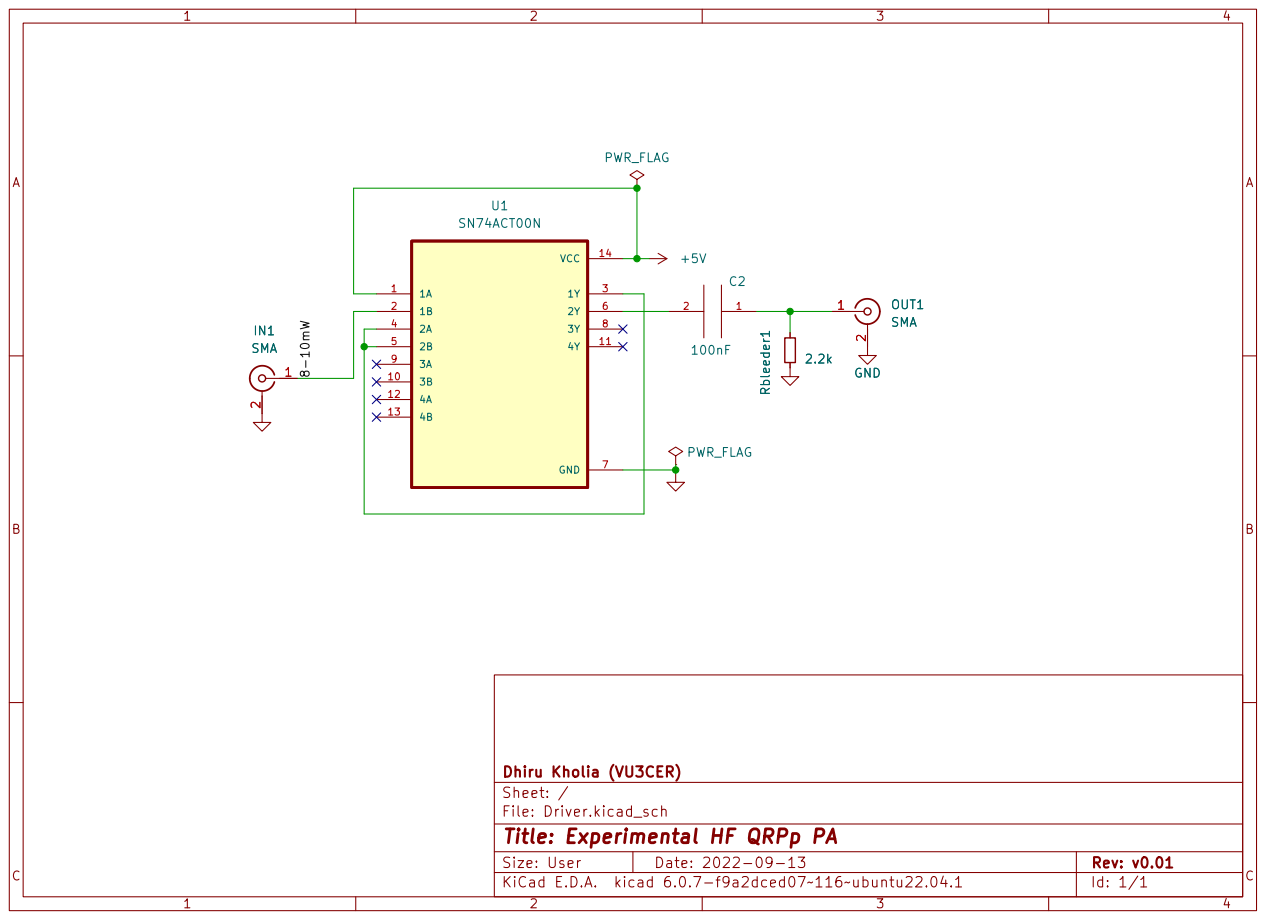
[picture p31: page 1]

File: Driver.kicad_sch Sheet: / Dhiru Kholia (VU3CER)

Id: 1/1 Title: Experimental HF QRPp PA

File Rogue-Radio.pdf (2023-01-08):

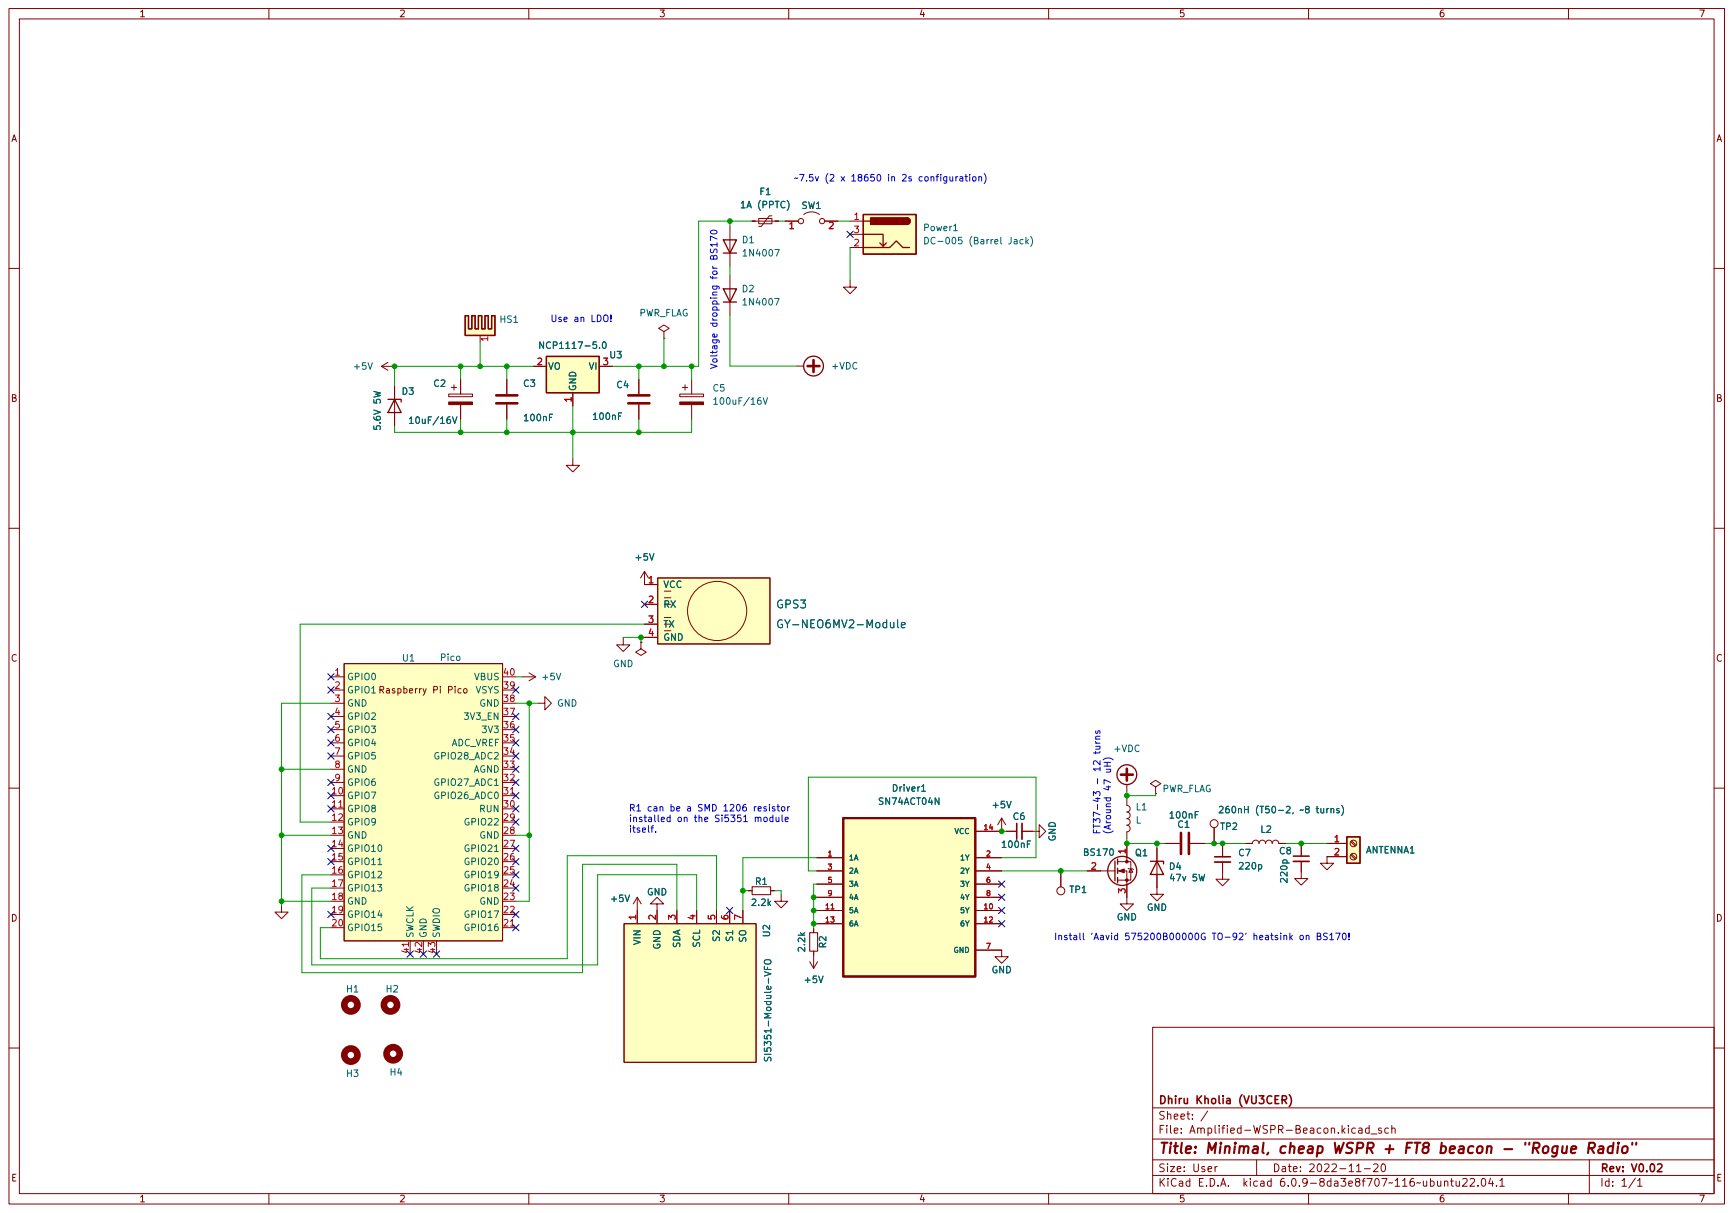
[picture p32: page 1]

~7.5v (2 x 18650 in 2s configuration) R1 can be a SMD 1206 resistor
1A (PPTC) C5

installed on the Si5351 module

2 GND GND
File: Amplified-WSPR-Beacon.kicad_sch Sheet: / Dhiru Kholia (VU3CER) 1

Install 'Aavid 575200B00000G TO-92' heatsink on BS170!

Id: 1/1 Title: Minimal, cheap WSPR + FT8 beacon - "Rogue Radio"

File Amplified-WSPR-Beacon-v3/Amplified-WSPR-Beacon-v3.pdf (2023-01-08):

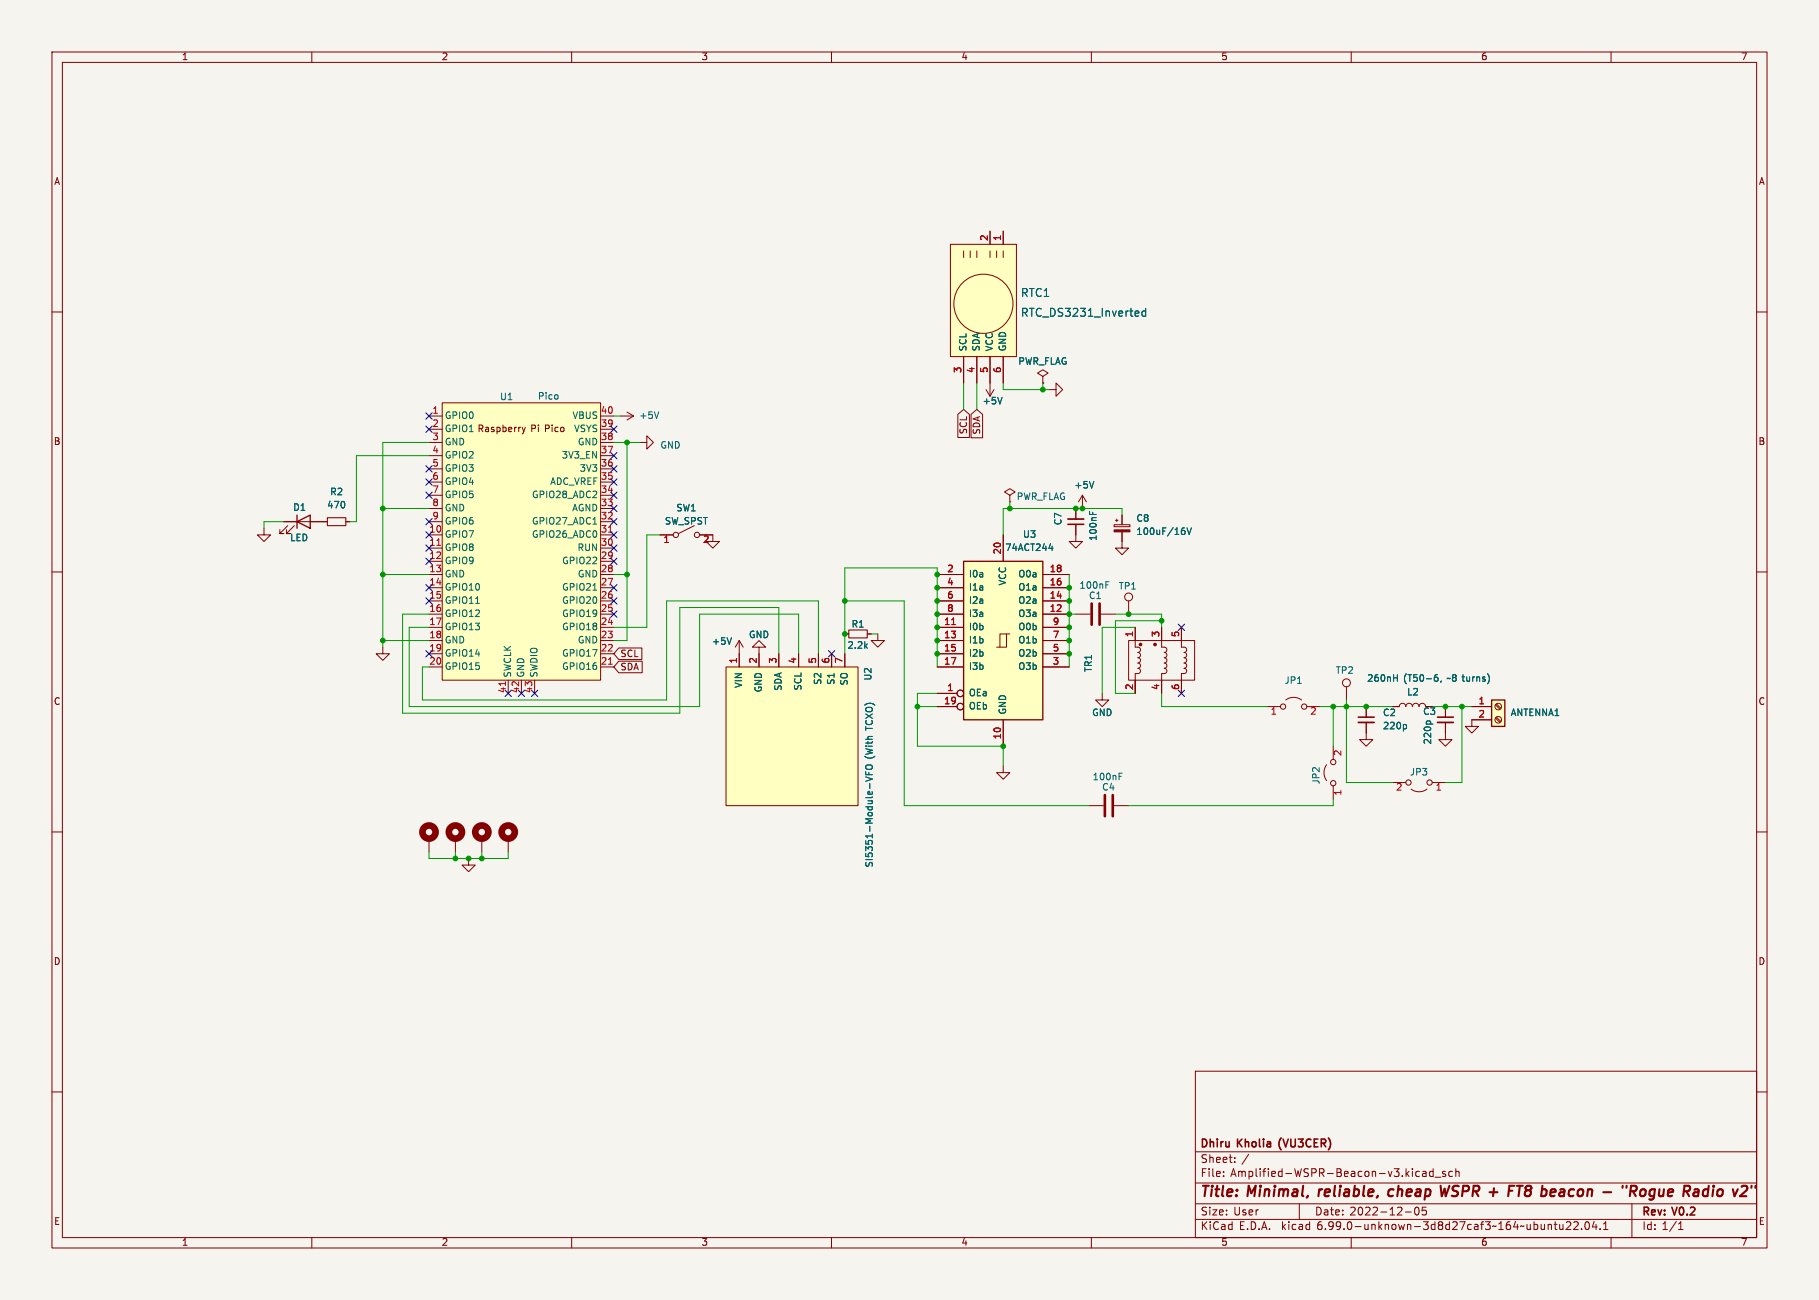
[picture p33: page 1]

7 U2 SI5351-Module-VFO (With TCXO) R1

File: Amplified-WSPR-Beacon-v3.kicad_sch Sheet: / Dhiru Kholia (VU3CER)

Id: 1/1 Title: Minimal, reliable, cheap WSPR + FT8 beacon - "Rogue Radio v2"

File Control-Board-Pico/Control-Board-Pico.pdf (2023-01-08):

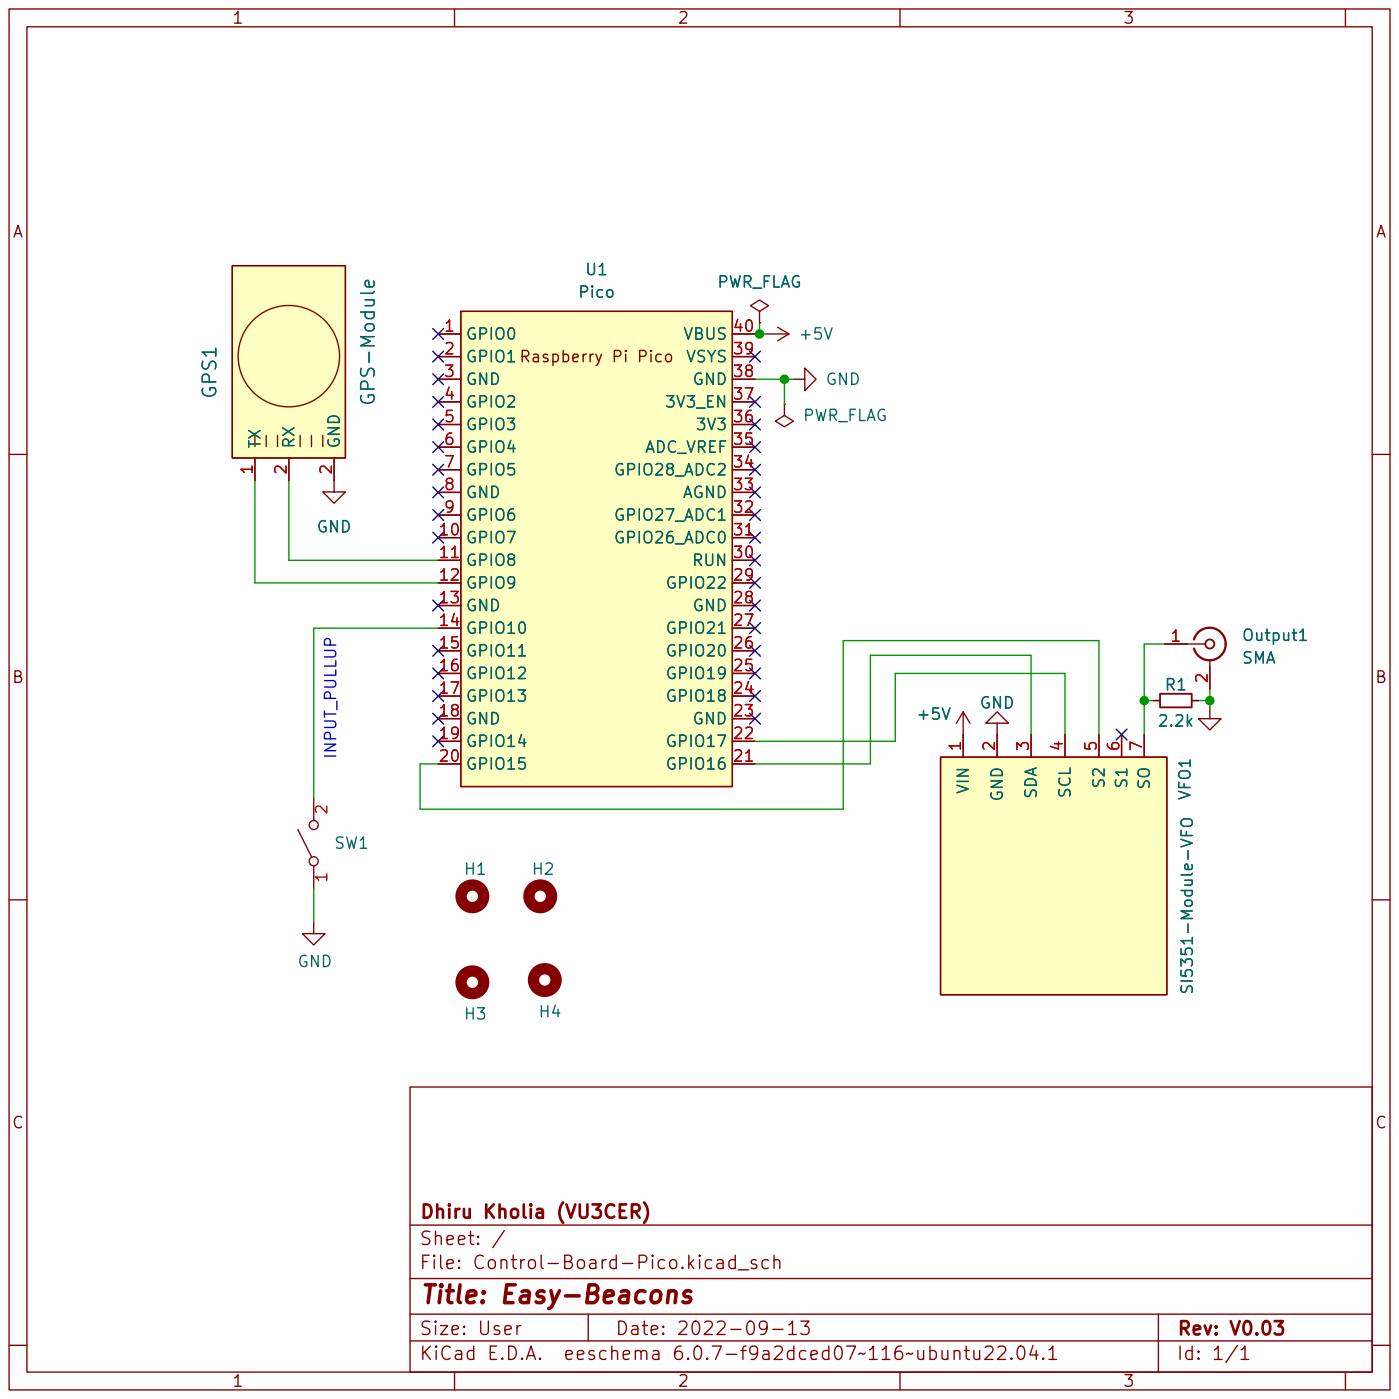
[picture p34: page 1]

2 U1 Pico GPIO0 1 GPIO7 10 GPIO8 11 GPIO9 12 GND 13 GPIO10 14 GPIO11 15 GPIO12 16 GPIO13 17 GND 18 GPIO14 19 GPIO1 2 GPIO15 20 GPIO16 21 GPIO17 22 GND 23 GPIO18 24 GPIO19 25 GPIO20 26 GPIO21 27 GND 28 GPIO22 29 GND 3 RUN 30 GPIO26_ADC0 31 GPIO27_ADC1 32 AGND 33 GPIO28_ADC2 34 ADC_VREF 35

Id: 1/1 Title: Easy-Beacons

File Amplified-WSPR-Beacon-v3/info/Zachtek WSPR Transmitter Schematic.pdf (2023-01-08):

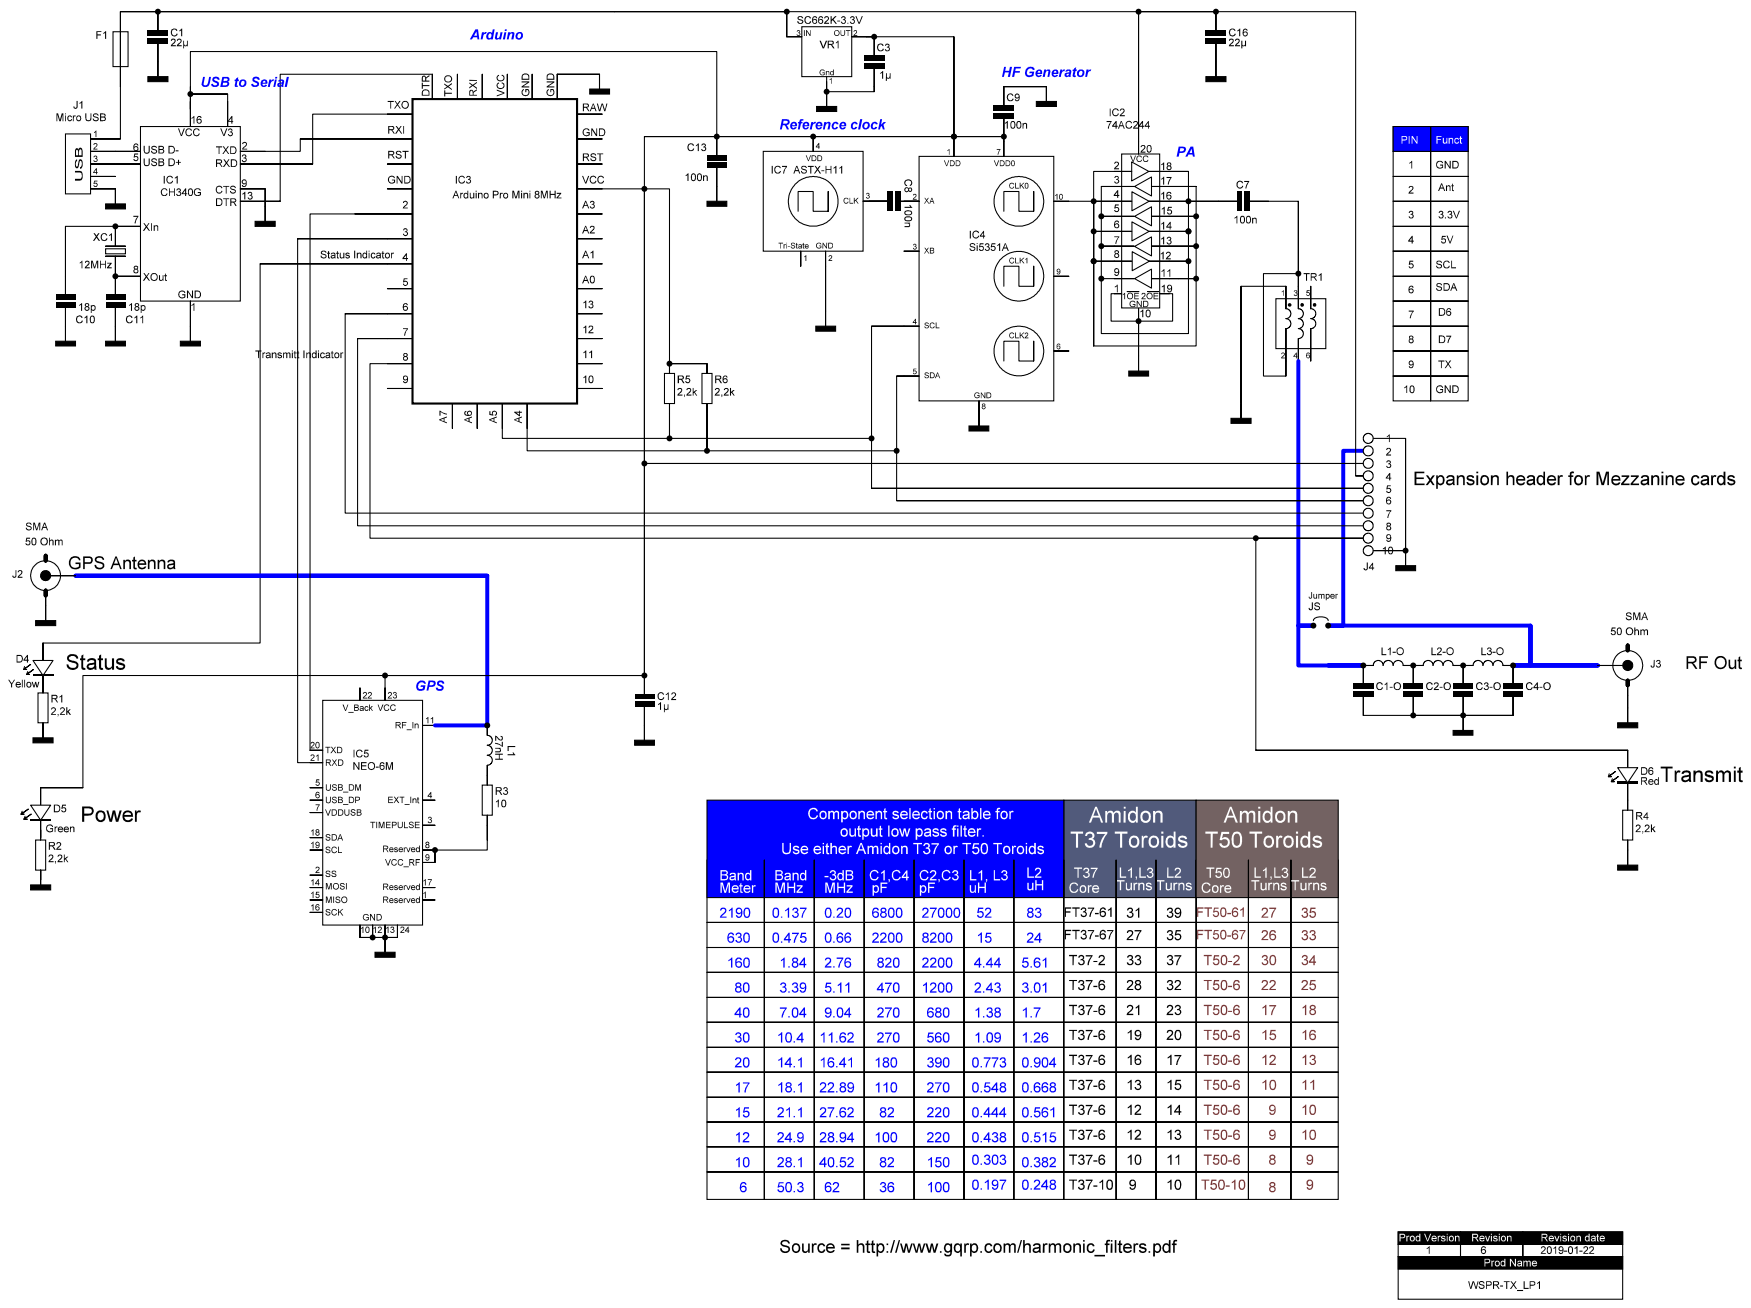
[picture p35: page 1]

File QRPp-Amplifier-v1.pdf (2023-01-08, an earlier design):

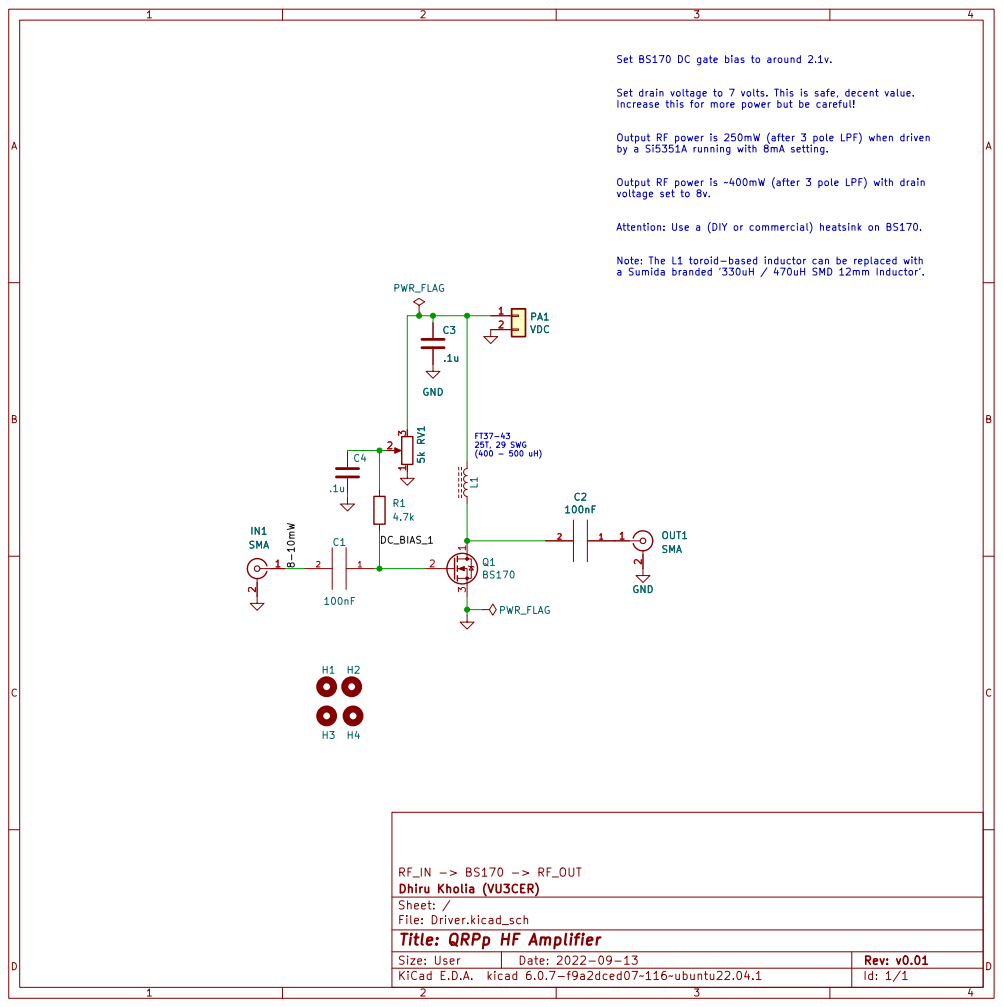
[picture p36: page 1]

Set drain voltage to 7 volts. This is safe, decent value.
Increase this for more power but be careful!

Output RF power is 250mW (after 3 pole LPF) when driven
by a Si5351A running with 8mA setting.

Output RF power is ~400mW (after 3 pole LPF) with drain
voltage set to 8v.

Attention: Use a (DIY or commercial) heatsink on BS170.

Note: The L1 toroid-based inductor can be replaced with
a Sumida branded '330uH / 470uH SMD 12mm Inductor'.

RF_IN -> BS170 -> RF_OUT
File: Driver.kicad_sch Sheet: / Dhiru Kholia (VU3CER)

Id: 1/1 Title: QRPp HF Amplifier

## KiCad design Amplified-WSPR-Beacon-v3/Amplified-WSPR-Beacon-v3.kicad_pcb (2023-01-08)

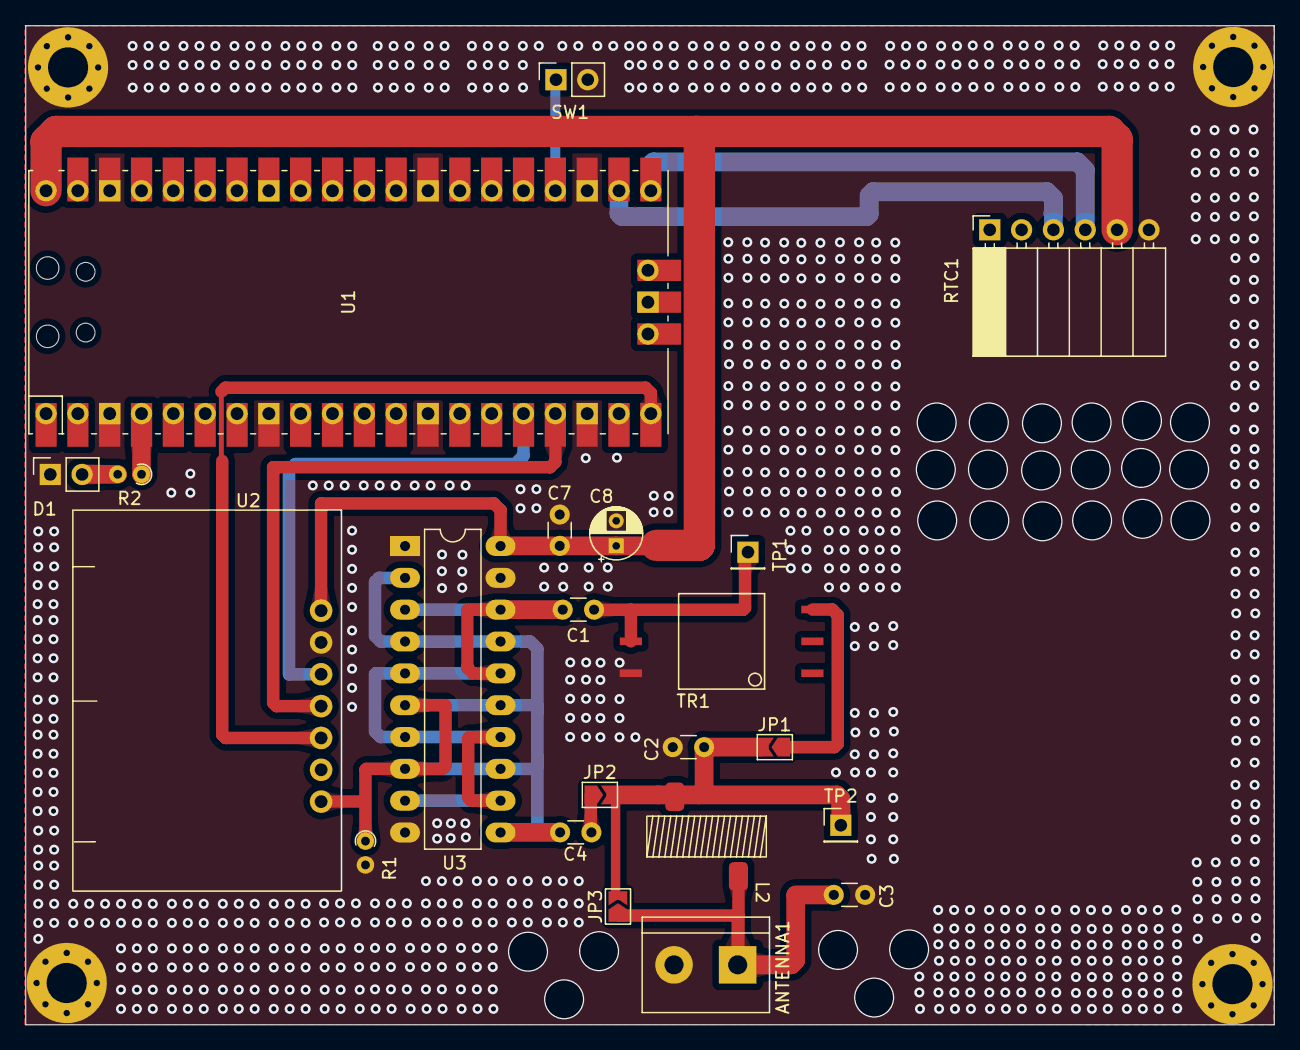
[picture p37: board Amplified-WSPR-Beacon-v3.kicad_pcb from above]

Board: 2 copper layers, 99.6 x 79.7 mm, 26 parts (0 on the bottom side), 17 nets.

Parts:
ANTENNA1: Screw_Terminal_01x02; TerminalBlock_bornier-2_P5.08mm
C1, C4, C7: 100nF; C_Disc_D3.0mm_W1.6mm_P2.50mm
C2, C3: 220p; C_Disc_D3.0mm_W1.6mm_P2.50mm
C8: 100uF/16V; CP_Radial_D4.0mm_P2.00mm
D1: LED; PinSocket_1x02_P2.54mm_Vertical
H1, H2, H3, H4: MountingHole_Pad; MountingHole_3.2mm_M3_Pad_Via
JP1, JP2, JP3: Jumper_2_Open; SolderJumper-2_P1.3mm_Open_TrianglePad1.0x1.5mm
L2: 260nH (T50-6, ~8 turns); T37-2
R1: 2.2k; R_Axial_DIN0204_L3.6mm_D1.6mm_P1.90mm_Vertical
R2: 470; R_Axial_DIN0204_L3.6mm_D1.6mm_P1.90mm_Vertical
RTC1: RTC_DS3231_Inverted; PinSocket_1x06_P2.54mm_Horizontal
SW1: SW_SPST; PinSocket_1x02_P2.54mm_Vertical
TP1, TP2: TestPoint; PinHeader_1x01_P2.54mm_Vertical
TR1: T2-613-1+; KK81
U1: Pico; RPi_Pico_SMD_TH
U2: SI5351-Module-VFO (With TCXO); SI5351 Module
U3: 74ACT244; DIP-20_W7.62mm_LongPads

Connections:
+5V: C7.2, C8.1, RTC1.5 (VCC), U1.40 (VBUS), U2.1 (VIN), U3.20 (VCC)
GND: ANTENNA1.2, C2.2, C3.2, C7.1, C8.2, D1.1 (K), H1.1, H2.1, H3.1, H4.1, R1.2, RTC1.6 (GND), SW1.2 (B), TR1.1, U1.3 (GND), U1.8 (GND), U1.13 (GND), U1.18 (GND), U1.23 (GND), U1.28 (GND), U1.38 (GND), U2.2 (GND), U3.1 (OEa), U3.10 (GND), U3.19 (OEb)
unnamed: ANTENNA1.1, C3.1, JP3.1 (A), L2.2
unnamed: C1.1, TP1.1, TR1.2, TR1.3
unnamed: D1.2 (A), R2.2
unnamed: JP1.1 (A), TR1.4
unnamed: C2.1, JP1.2 (B), JP2.2 (B), JP3.2 (B), L2.1, TP2.1
unnamed: C4.1, JP2.1 (A)
unnamed: SW1.1 (A), U1.24 (GPIO18)
unnamed: R2.1, U1.4 (GPIO2)
unnamed: U1.16 (GPIO12), U2.3 (SDA)
unnamed: U1.17 (GPIO13), U2.4 (SCL)
unnamed: U1.20 (GPIO15), U2.5 (S2)
unnamed: C4.2, R1.1, U2.7 (SO), U3.2 (I0a), U3.4 (I1a), U3.6 (I2a), U3.8 (I3a), U3.11 (I0b), U3.13 (I1b), U3.15 (I2b), U3.17 (I3b)
unnamed: C1.2, U3.3 (O3b), U3.5 (O2b), U3.7 (O1b), U3.9 (O0b), U3.12 (O3a), U3.14 (O2a), U3.16 (O1a), U3.18 (O0a)
SCL: RTC1.3 (SCL), U1.22 (GPIO17)
SDA: RTC1.4 (SDA), U1.21 (GPIO16)

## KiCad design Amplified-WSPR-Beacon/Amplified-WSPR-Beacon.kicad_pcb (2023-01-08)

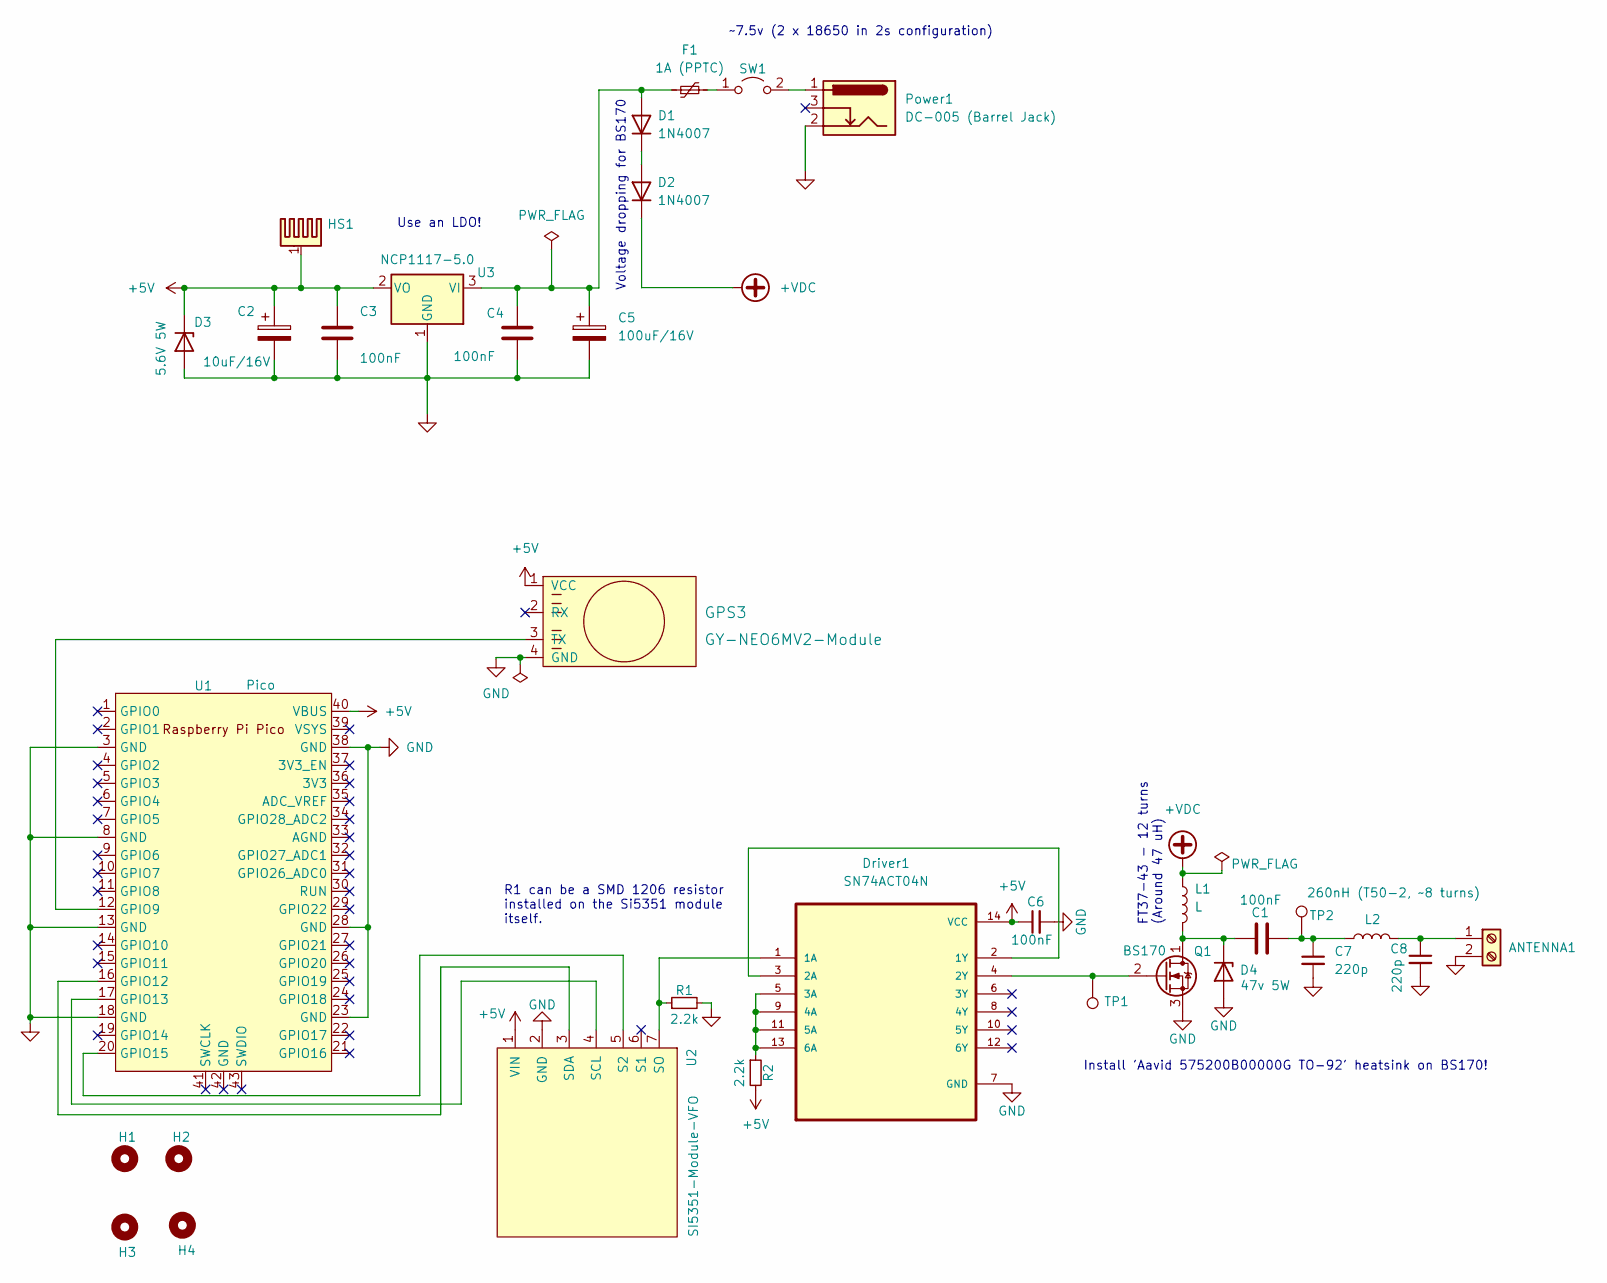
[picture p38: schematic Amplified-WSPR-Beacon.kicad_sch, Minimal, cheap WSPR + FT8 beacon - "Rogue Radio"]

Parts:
ANTENNA1: Screw_Terminal_01x02; TerminalBlock_bornier-2_P5.08mm
C1, C3, C4, C6: 100nF; C_1206_3216Metric_Pad1.33x1.80mm_HandSolder
C2: 10uF/16V; CP_Radial_D4.0mm_P2.00mm
C5: 100uF/16V; CP_Radial_D4.0mm_P2.00mm
C7, C8: 220p; C_1206_3216Metric_Pad1.33x1.80mm_HandSolder
D1, D2: 1N4007; D_DO-41_SOD81_P2.54mm_Vertical_KathodeUp
D3: 5.6V 5W; D_DO-15_P5.08mm_Vertical_KathodeUp
D4: 47v 5W; D_DO-15_P5.08mm_Vertical_KathodeUp
Driver1: SN74ACT04N; DIP-14_W7.62mm
F1: 1A (PPTC); Fuse_1812_4532Metric_Pad1.30x3.40mm_HandSolder
GPS3: GY-NEO6MV2-Module; PinSocket_1x04_P2.54mm_Vertical
H1, H2, H3, H4: MountingHole; MountingHole_3.2mm_M3
HS1: Heatsink_Pad; ThermalPad_Final
L1: L; FT37-INDUCTOR
L2: 260nH (T50-2, ~8 turns); FT37-INDUCTOR
Power1: DC-005 (Barrel Jack); XKB_DC-005-5A-2.0_Modded
Q1: BS170; PinSocket_1x03_P2.54mm_Vertical
R1, R2: 2.2k; R_1206_3216Metric_Pad1.30x1.75mm_HandSolder
SW1: Jumper_2_Open; PinSocket_1x02_P2.54mm_Vertical
TP1, TP2: TestPoint; PinHeader_1x01_P2.54mm_Vertical
U1: Pico; RPi_Pico_SMD_TH
U2: SI5351-Module-VFO; SI5351 Module
U3: NCP1117-5.0; SOT-223-3_TabPin2

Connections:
+5V: C2.1, C3.1, C6.1, D3.1 (K), Driver1.14 (VCC), GPS3.1 (VCC), HS1.1, R2.2, U1.40 (VBUS), U2.1 (VIN), U3.2 (VO)
+VDC: D2.1 (K), L1.1
GND: ANTENNA1.2, C2.2, C3.2, C4.2, C5.2, C6.2, C7.2, C8.2, D3.2 (A), D4.2 (A), Driver1.7 (GND), GPS3.4 (GND), Power1.2, Q1.3 (S), R1.2, U1.3 (GND), U1.8 (GND), U1.13 (GND), U1.18 (GND), U1.23 (GND), U1.28 (GND), U1.38 (GND), U2.2 (GND), U3.1 (GND)
unnamed: ANTENNA1.1, C8.1, L2.2
unnamed: C1.1, C7.1, L2.1, TP2.1
unnamed: C1.2, D4.1 (K), L1.2, Q1.1 (D)
unnamed: C4.1, C5.1, D1.2 (A), F1.1, U3.3 (VI)
unnamed: D1.1 (K), D2.2 (A)
unnamed: Driver1.1 (1A), R1.1, U2.7 (SO)
unnamed: Driver1.2 (1Y), Driver1.3 (2A)
unnamed: Driver1.4 (2Y), Q1.2 (G), TP1.1
unnamed: Driver1.5 (3A), Driver1.9 (4A), Driver1.11 (5A), Driver1.13 (6A), R2.1
unnamed: F1.2, SW1.1 (A)
unnamed: GPS3.3 (TX), U1.12 (GPIO9)
unnamed: Power1.1, SW1.2 (B)
unnamed: U1.16 (GPIO12), U2.3 (SDA)
unnamed: U1.17 (GPIO13), U2.4 (SCL)
unnamed: U1.20 (GPIO15), U2.5 (S2)

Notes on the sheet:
Install 'Aavid 575200B00000G TO-92' heatsink on BS170!
FT37-43 - 12 turns (Around 47 uH)
Use an LDO!
Voltage dropping for BS170
R1 can be a SMD 1206 resistor installed on the Si5351 module itself.
~7.5v (2 x 18650 in 2s configuration)

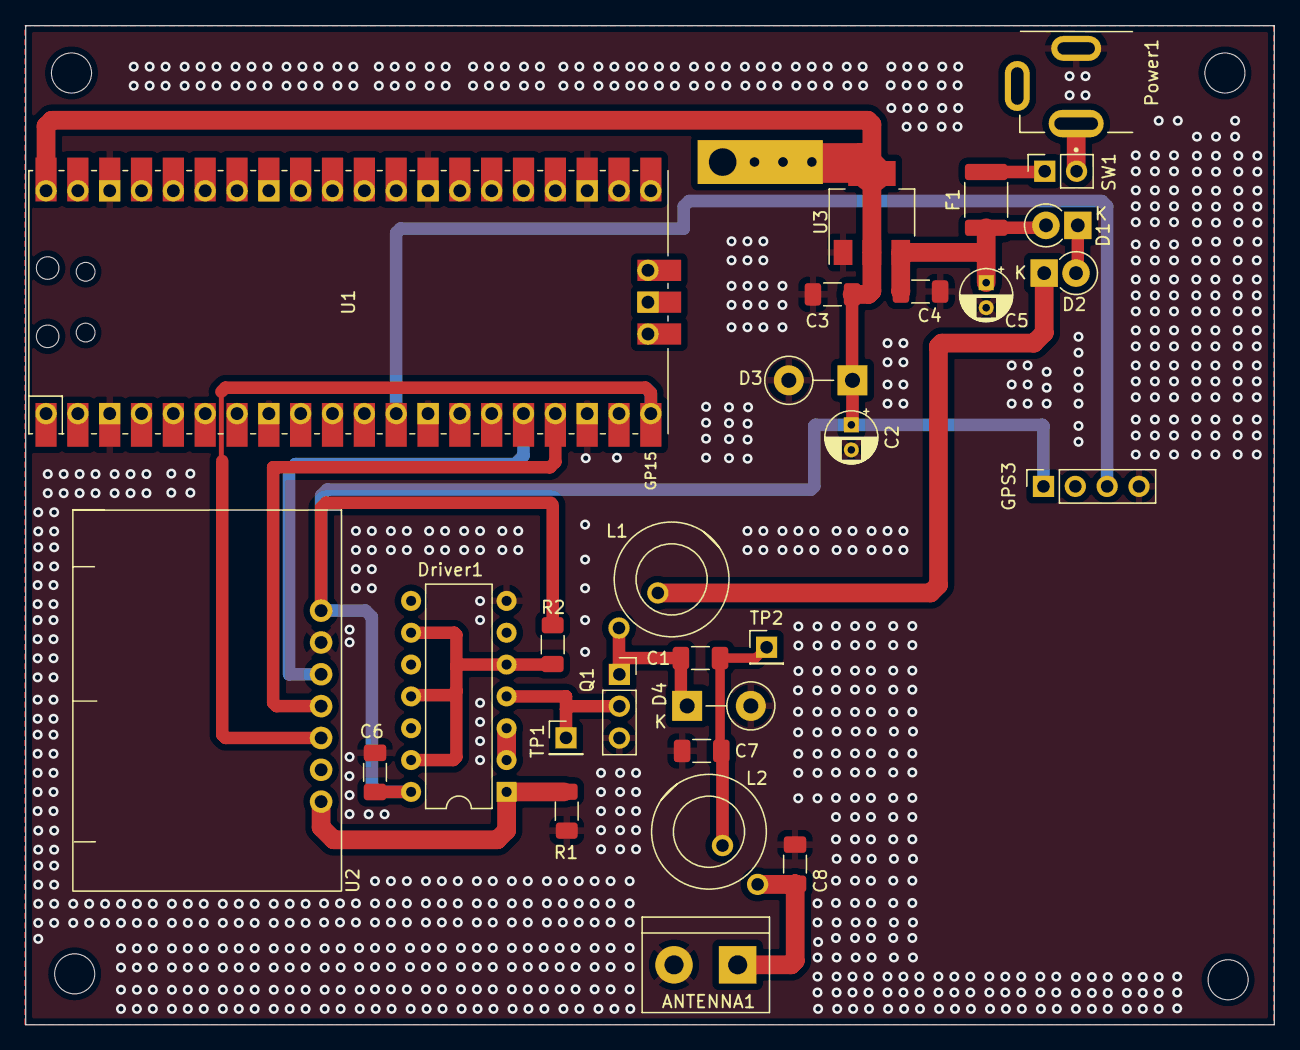
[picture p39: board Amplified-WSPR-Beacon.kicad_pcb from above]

Board: 2 copper layers, 99.6 x 79.7 mm, 33 parts (0 on the bottom side), 18 nets.

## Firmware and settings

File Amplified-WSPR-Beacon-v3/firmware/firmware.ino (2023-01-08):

// Runs on Raspberry Pi Pico W
//
// Capable of running off the RTC without internet once RTC is synced

#include <Wire.h>
#include <si5351.h>
#include <Arduino.h>
#include <TimeLib.h>
#include <JTEncode.h>

// WiFI
#include <WiFi.h>
#include "credentials.h"
WiFiMulti multi;

// RTC
#include <RTClib.h>
RTC_DS3231 rtc;
DateTime dt;
int rtc_lost_power = 0;

#include "pico/stdlib.h"
#include "pico/time.h"
#include "hardware/irq.h"  // interrupts
#include "hardware/pwm.h"  // pwm
#include "hardware/sync.h" // wait for interrupt

// Internals
int build_number = 1;

// Si5351 stuff
Si5351 si5351;
int32_t si5351CalibrationFactor = 0; // This is automatically derived!

long long frequency = 28126100 * 100UL; // CHANGE THIS PLEASE
long long new_frequency = 0;
uint8_t tones[255];
int toneDelay;
int symbolCount;
int toneSpacing;

// WSPR properties
#define WSPR_TONE_SPACING 146 // ~1.46 Hz
#define WSPR_DELAY 683 // Delay value for WSPR
char call[] = "VU3CER"; // CHANGE THIS PLEASE!
char loc[] = "MK68"; // CHANGE THIS PLEASE!
// https://physics.princeton.edu//pulsar/K1JT/doc/wspr/wspr-main.html#CONVERSION
uint8_t dbm = 23; // 200mW
JTEncode jtencode;

// Pins
#define EXTERNAL_LED 2 // GP2
#define FREQUENCY_INPUT_PIN 15
#define SW1 18
int buttonState = 0;
int previousButtonState = -1;

int encoder(char *message, uint8_t *tones, int is_ft4);

void tx(uint8_t *tones)
{
  uint8_t i;

  Serial.println("TX!");
  digitalWrite(LED_BUILTIN, HIGH);
  digitalWrite(EXTERNAL_LED, HIGH);
  si5351.set_clock_pwr(SI5351_CLK0, 1);
  si5351.output_enable(SI5351_CLK0, 1);

  for (i = 0; i < symbolCount; i++)
  {
    si5351.set_freq(frequency + (tones[i] * toneSpacing), SI5351_CLK0);
    delay(toneDelay);
  }

  // Turn off the output
  si5351.set_clock_pwr(SI5351_CLK0, 0);
  si5351.output_enable(SI5351_CLK0, 0);
  digitalWrite(LED_BUILTIN, LOW);
  digitalWrite(EXTERNAL_LED, LOW);
}

// Automatic calibration
uint32_t f_hi;

void pwm_int() {
  pwm_clear_irq(7);
  f_hi++;
}

void do_calibration()
{
  int64_t existing_error = 0;
  int64_t error = 0;
  int count = 3; // reverse count
  uint64_t target_freq = 1000000000ULL; // 10 MHz, in hundredths of hertz

  // Warmup
  Serial.println("Warming up....");
  delay(7000);

  uint32_t f = 0;
  // Frequency counter
  while (true) {
    count = count - 1;
    pwm_config cfg = pwm_get_default_config();
    pwm_config_set_clkdiv_mode(&cfg, PWM_DIV_B_RISING);
    pwm_init(7, &cfg, false);
    gpio_set_function(FREQUENCY_INPUT_PIN, GPIO_FUNC_PWM);
    pwm_set_irq_enabled(7, true);
    irq_set_exclusive_handler(PWM_IRQ_WRAP, pwm_int);
    irq_set_enabled(PWM_IRQ_WRAP, true);
    f_hi = 0;
    si5351.set_correction(0, SI5351_PLL_INPUT_XO); // important - reset calibration
    uint32_t t = time_us_32() + 2;
    while (t > time_us_32());
    pwm_set_enabled(7, true);
    t += 3000000; // Gate time (in uSeconds), 3 seconds
    // t += 100000; // Gate time (in uSeconds), 100 ms
    while (t > time_us_32());
    pwm_set_enabled(7, false);
    f = pwm_get_counter(7);
    f += f_hi << 16;
    Serial.print(f / 3.0); // Divide by gate time in seconds
    Serial.println(" Hz");
    error = ((f / 3.0) * 100ULL) - target_freq;
    Serial.print("Current calibration correction value is ");
    Serial.printf("%" PRId64 "\n", error);
    Serial.print("Total calibration value is ");
    Serial.println(error + existing_error);
    if (count <= 0) { // Auto-calibration logic
      Serial.println();
      Serial.print(F("Calibration value is "));
      Serial.println(error);
      Serial.println(F("Setting calibration value automatically"));
      si5351.set_correction(error + existing_error, SI5351_PLL_INPUT_XO);
      existing_error = existing_error + error;
      si5351.set_pll(SI5351_PLL_FIXED, SI5351_PLLA);
      Serial.println(F("Resetting target frequency"));
      si5351.set_freq(target_freq, SI5351_CLK2);
      // count = 3;
      break;
    }
  }

  // Let's keep CLK2 on to keep the chip warmed up!
}

// Debug helper
void led_flash()
{
  digitalWrite(LED_BUILTIN, HIGH);
  delay(250);
  digitalWrite(LED_BUILTIN, LOW);
  delay(250);
  digitalWrite(LED_BUILTIN, HIGH);
  delay(250);
  digitalWrite(LED_BUILTIN, LOW);
  delay(250);
  digitalWrite(LED_BUILTIN, HIGH);
  delay(250);
  digitalWrite(LED_BUILTIN, LOW);
  delay(250);
  digitalWrite(LED_BUILTIN, HIGH);
}

void setClock() {
  // NTP.begin("pool.ntp.org", "time.nist.gov");
  NTP.begin("time.cloudflare.com");

  Serial.print("Waiting for NTP time sync: ");
  time_t now = time(nullptr);
  while (now < 8 * 3600 * 2) {
    delay(500);
    Serial.print(".");
    now = time(nullptr);
  }
  Serial.println("");
  struct tm timeinfo;
  gmtime_r(&now, &timeinfo);
  // We just need the minute and the second fields to be accurate
  // setTime(hr, min, sec, day, mnth, yr);
  // https://cplusplus.com/reference/ctime/tm/
  // https://github.com/PaulStoffregen/Time/blob/master/TimeLib.h#L34
  setTime(now);
  rtc.adjust(now);
  Serial.print("Current time: ");
  Serial.print(asctime(&timeinfo));
  Serial.println(timeStatus());
}

void setup() {
  int ret = 0;
  char date[10] = "hh:mm:ss";

  // Setup I/O pins
  pinMode(FREQUENCY_INPUT_PIN, INPUT);
  pinMode(LED_BUILTIN, OUTPUT);
  pinMode(EXTERNAL_LED, OUTPUT);
  pinMode(SW1, INPUT_PULLUP);
  Serial.begin(115200);
  delay(5000);

  Serial.printf("Device is configured with (%s %s %d) settings...\n", call, loc, dbm);
  Serial.printf("Device is configured with (%s %s %d) settings...\n", call, loc, dbm);
  Serial.printf("Device is configured with (%s %s %d) settings...\n", call, loc, dbm);

  // I2C pins
  Wire.setSDA(12);
  Wire.setSCL(13);
  Wire.begin();

  // Initialize the Si5351
  ret = si5351.init(SI5351_CRYSTAL_LOAD_8PF, 0, si5351CalibrationFactor);
  if (ret != true) {
    led_flash();
    watchdog_reboot(0, 0, 1000);
  }
  si5351.set_clock_pwr(SI5351_CLK0, 0); // Safety first

  // Initialize the rtc
  if (!rtc.begin()) {
    Serial.println("Couldn't find RTC!");
    Serial.flush();
    abort();
  }
  if (rtc.lostPower()) {
    Serial.println("RTC lost power, abort!?");
    Serial.flush();
    rtc_lost_power = 1;
    led_flash();
    delay(50);
    // rtc.adjust(DateTime(F(__DATE__), F(__TIME__))); // hack!
    // abort();  // NOTE
  }
  rtc.disable32K();
  rtc.now().toString(date);

  // WiFI + NTP (https://arduino-pico.readthedocs.io/en/latest/wifintp.html)
  buttonState = digitalRead(SW1);
  if (buttonState == HIGH) {
    Serial.println();
    Serial.println();
    Serial.print("Connecting to ");
    Serial.println(ssid);
    multi.addAP(ssid, password);
    if (multi.run() != WL_CONNECTED) {
      Serial.println("Unable to connect to network, using time from DS3231...");
      // delay(10000);
      // rp2040.reboot();
    } else {
      Serial.println("");
      Serial.println("WiFi connected");
      Serial.println("IP address: ");
      Serial.println(WiFi.localIP());
      setClock();
    }
  }

  // Set CLK0 output
  si5351.drive_strength(SI5351_CLK0, SI5351_DRIVE_2MA); // Set for minimum power as we have an external amplifier
  si5351.set_clock_pwr(SI5351_CLK0, 0); // Disable the clock initially
  si5351.output_enable(SI5351_CLK0, 0);
  si5351.drive_strength(SI5351_CLK2, SI5351_DRIVE_2MA); // Output current 2/4/6/8 mA
  si5351.set_freq(10000000 * 100ULL, SI5351_CLK2); // Used for calibration
  si5351.output_enable(SI5351_CLK0, 0);
  si5351.output_enable(SI5351_CLK2, 1);

  // Perform automatic calibration
  do_calibration();
  si5351.output_enable(SI5351_CLK0, 0);
  // si5351.set_clock_pwr(SI5351_CLK2, 0);
  // si5351.output_enable(SI5351_CLK2, 0);

  // Prep for WSPR
  jtencode.wspr_encode(call, loc, dbm, tones);
  toneDelay = WSPR_DELAY;
  toneSpacing = WSPR_TONE_SPACING;
  symbolCount = WSPR_SYMBOL_COUNT;
}

int incomingByte = 0; // for incoming serial data

// CAT code
static byte insideCat = 0;
unsigned char doingCAT = 0;
bool message_available = false;
#define CAT_MAX 24
static char cat[CAT_MAX + 64]; // 64 avoids overflow
static int sidx = 0; // serial index
char current_message[32];

void loop() {
  uint32_t count = Serial.available();

  if (count > 0) {
    for (int i = 0; i < count; i++) {
      cat[sidx] = Serial.read();
      sidx = sidx + 1;
    }
    cat[CAT_MAX - 1] = 0;
    sidx = (sidx + count) % CAT_MAX; // not perfect
    incomingByte = Serial.read();

    // Protocol -> a valid message starts with '*' and also ends with '*'
    char *s = strchr(cat, '*');
    char *e = strrchr(cat, '*');
    if (s != e && s != NULL && e != NULL ) { /* We may have a valid message */
      if (*(s + 1) == 'v') {
        Serial.print("r");
      } else if (*(s + 1) == 'p') {
        Serial.print('p');
      } else if (*(s + 1) == 'u') {
        char *response = (char *)"m";
        message_available = true;
        strncpy(current_message, strtok(s + 2, "*"), 32 - 1);
        Serial.println(current_message);
      } else if (*(s + 1) == 't') {
        if (message_available) {
          // char *response = (char *)"t";
          // Serial2.println("TX!");
        }
      } else if (*(s + 1) == 'z') {
        if (message_available) {
          char *response = (char *)"z";
          Serial2.println("PTT OFF");
        }
      } else if (*(s + 1) == 'y') {
        if (message_available) {
          char *response = (char *)"y";
        }
      } else if (*(s + 1) == 'f') {
        char *response = (char *)"f";
        char *f = strtok(s + 2, "*");
        char *ptr;
        new_frequency = strtoul(f, &ptr, 10);
      }
      // Clear stuff
      sidx = 0;
      memset(cat, 0, CAT_MAX * 2);
    }
  }

  if (minute () % 2 == 0 && second() % 60 == 0)  {
    // empirically calculated start delay
    delay(400);
    tx(tones);
  }

  delay(10);
}
